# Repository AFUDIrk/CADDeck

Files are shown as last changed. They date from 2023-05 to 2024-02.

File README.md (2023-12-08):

# CADdeck
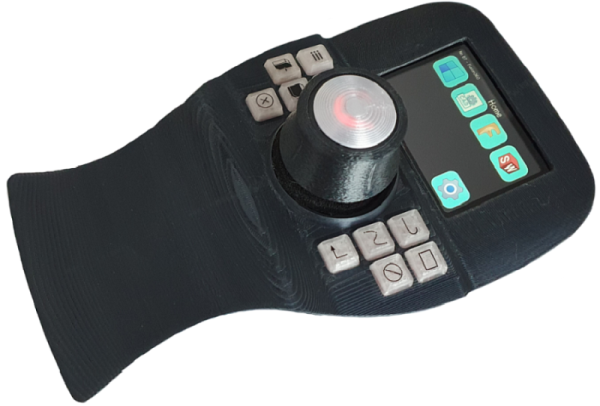
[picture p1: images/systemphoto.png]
Systemfoto


The english [Manual](/READMEeng.md) 

Hierbei handelt es sich um ein kombiniertes Joystick- und Touchpanel-Display, das für die Verwendung mit gängigen CAD-Programmen geeignet ist. Es beinhaltet:
1. Zwei-Achsen-Joystick (z. B. für X-, Y-Schwenk)
2. Hall-Sensoren im Joystick-Griff (z. B. für Zoom und Drehung) mit einem berührungslosen Sensor (z. B. zum Bewegen der Komponente in Kombination mit dem Joystick)
3. Zehn Schalter rund um die Basis (z. B. Messen, ESC...)
4. LCD-Touchpanel mit bis zu 10 Bildschirmen und 12 Tasten

Alle H/W-Tasten und die Touchpanel-Tasten sind über eine Website programmierbar.

Die Verbindung zum PC erfolgt per Bluetooth über die HID-Schnittstelle (d. h. für den PC sieht es aus wie eine Tastatur und eine Maus).
Für die Stromversorgung und das Herunterladen von Code steht ein USB-C-Anschluss zur Verfügung.
Der USB-C-Anschluss auf der Rückseite dient der Stromversorgung zum Hochladen des Codes.
Es sollte möglich sein, das Gerät mit Strom zu versorgen und es fest mit dem Bildschirm zu verbinden, anstatt es über USB-C mit Strom zu versorgen, aber das habe ich noch nicht versucht.

Es wurde von Andrew eine USB-Schnitstelle mit einem RP2040 hinzugefügt, mit der das CADDeck 6DOF fähig ist. Es wird noch daran gearbeitet, den Code so zu ändern,
das nur noch ein Prozessor gebraucht wird. Momentan ist noch eine Bluetooth- und eine USB-Verbindung nötig, damit das ganze funktioniert.

Die Firmware für den RP2040 ist von https://github.com/jfedor2/magellan-spacemouse.
Die Version für das CADDeck ist hier zu finden: https://github.com/AFUDIrk/magellan-spacemouse

## Touch-Panel
Das Touchpanel ist von Dustin Watts FreeTouchDeck-Projekt (https://github.com/DustinWatts/FreeTouchDeck.git) inspiriert, das ich modifiziert habe, um die Anzahl der Tasten zu erhöhen.
usw. (https://github.com/andrewfernie/FreeTouchDeckWT32.git). Für dieses Projekt habe ich Joystick-, Hallsensor- und Tastenunterstützung hinzugefügt.
Der einfachste Weg, dies in Gang zu bringen, ist die Verwendung einer WT32-SC01-Karte (http://www.wireless-tag.com/portfolio/wt32-sc01/).
Kaufen Sie das Basisboard, nicht die „Plus“-Version, da das Plus eine parallele Schnittstelle zum LCD-Panel nutzt und nicht genügend IO-Leitungen für den Joystick und die Tasten frei lässt.
usw. Das Board enthält ein ESP32-Modul und ein 3,5-Zoll-LCD mit kapazitivem Touchscreen.

## S/W-Aufbau-Hinweise:
1. Der Build verwendet die PlatformIO-IDE für VSCode. Installieren Sie VSCode, dann das PlatformIO-Plugin und schon kann es losgehen.
2. Sie müssen sicherstellen, dass die entsprechenden Pins für Ihre Hardwarekonfiguration definiert sind. Ich habe meines für den WT32-SC01 gebaut und den Code für ein handverdrahtetes ESP32-Modul + einen resistiven Touchscreen erstellt.
3. Möglicherweise sehen Sie Build-Meldungen wie
 
In der Datei, die aus include/CADDeck.h:14 enthalten ist,
aus include/SaveConfig.h:3,
von src/SaveConfig.cpp:1:
.pio/libdeps/esp-wrover-kit/TFT_eSPI/TFT_eSPI.h:909:8: Warnung: #warning >>>>------>> TOUCH_CS-Pin nicht definiert, TFT_eSPI-Touchfunktionen sind nicht zugänglich! [-Wcpp]
#Warnung >>>>------>> TOUCH_CS-Pin nicht definiert, TFT_eSPI-Touchfunktionen sind nicht verfügbar!`
 
Sie können diese beseitigen, indem Sie TOUCH_CS in platformio.ini für jeden nicht verwendeten Pin definieren, der ein gültiger Ausgabepin ist.
Die Alternative besteht darin, TOUCH_CS nicht zu definieren (die Zeile löschen oder ein Semikolon davor einfügen) und die Meldungen einfach zu ignorieren.

#define TOUCH_CS=33

4. Das System versucht beim Start, das Logo in CADDeck_logo.bmp anzuzeigen. Wenn Sie nicht möchten, dass etwas angezeigt wird, stellen Sie sicher, dass die Datei nicht existiert. In diesem Fall wird auf der seriellen Schnittstelle eine Meldung wie die folgende angezeigt.
Solange Sie beim Start nichts gesehen haben, ignorieren Sie die Meldung.
 
[ 1159][E][vfs_api.cpp:104] open(): /littlefs/logos/CADDeck_logo.bmp existiert nicht, keine Berechtigungen zum Erstellen

5. Möglicherweise werden Ihnen Fehlermeldungen wie z. B. angezeigt
 
[vfs_api.cpp:104] open(): /littlefs/list existiert nicht
 
Dies ist ein bekanntes Problem mit ESPAsyncWebsServer im Zusammenhang mit von LittleFS unterstützten Ordnern, während dies bei SPIFFS nicht der Fall ist. Siehe https://github.com/lorol/

6. Haben Sie Probleme? Es gibt einige Debug-Meldungen, die in FreeTouchDeck.h aktiviert werden können
 
#define LOG_MSG_BASIC 1
#define LOG_MSG_LEVEL 1 // 1=FEHLER, 2=FEHLER+WARN, 3=FEHLER+WARN+INFO
#define LOG_MSG_DEBUG 0
#define LOG_MSG_TOUCH_DEBUG 0 // Meldungen an die Konsole jedes Mal, wenn eine Berührung erkannt wird

Versuchen Sie, LOG_MSG_LEVEL auf 3 zu setzen, und Sie erhalten weitere Statusmeldungen

# Hardware-Aufbau

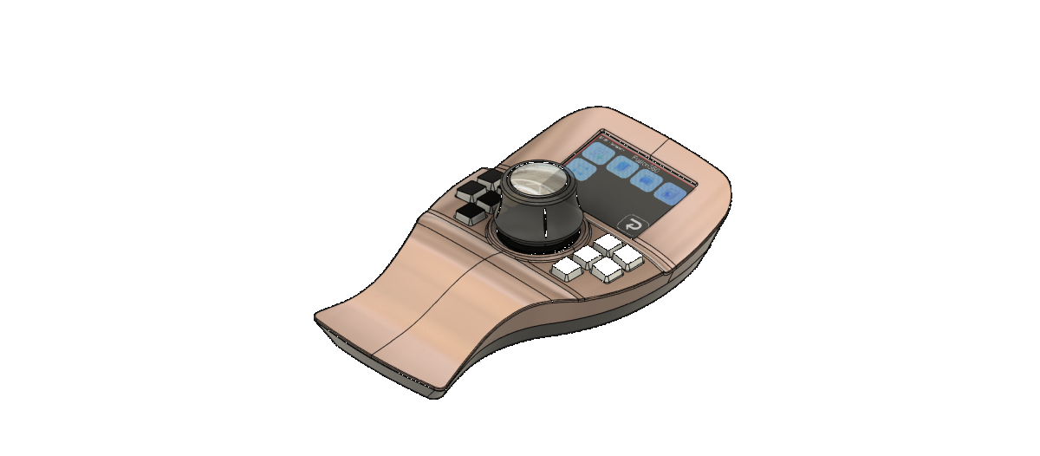
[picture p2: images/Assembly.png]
Assembly


Der größte Teil der Montage ist einfach und besteht größtenteils aus der Verkabelung.
Vollständige 3D-CAD-Modelle werden sowohl im Fusion360- als auch im STEP-Format im Ordner „hardware/model“ bereitgestellt.

Die Verweise auf Tastennummern werden in diesem Diagramm angezeigt:

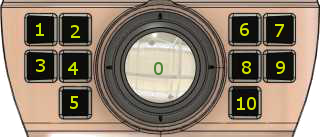
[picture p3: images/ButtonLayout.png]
Schaltflächennummern


## Gehäuse
Ein Fusion360-Modell des Falls und STL-Dateien sind im CADDeck-Repository enthalten. Das Hauptgehäuse ist zweiteilig bedruckt.
Das Ober- und Unterteil wird von unten mit M3-Kopfschrauben verschraubt.

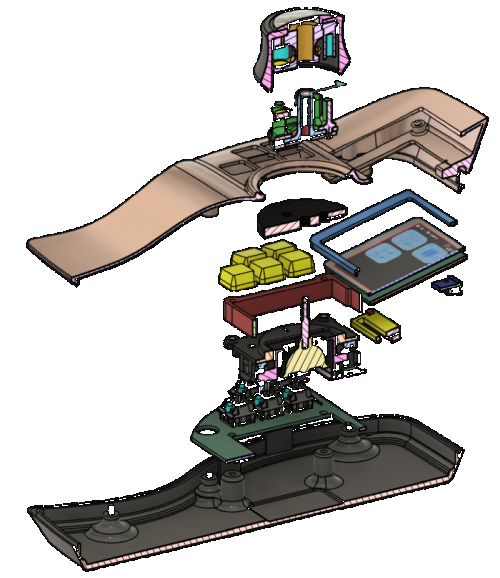
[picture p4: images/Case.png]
Case


Es gibt keine offensichtliche Möglichkeit, den Bildschirm am Gehäuse zu befestigen. Deshalb habe ich das Gehäuse so entworfen, dass es das Display mit einem Rahmen hält.
Zuerst wird das Display in das Gehäuse geschoben, bis es in den hinteren Abstandshaltern einrastet.
Anschließend wird die TPU-Dichtung zwischen Gehäuse und Display geschoben und abschließend die beiden vorderen Abstandshalter eingefügt.
Bei Bedarf kann das Display mit zwei Schrauben von hinten gegen die TPU-Dichtung gedrückt werden.
Aber war bei mir nicht nötig.

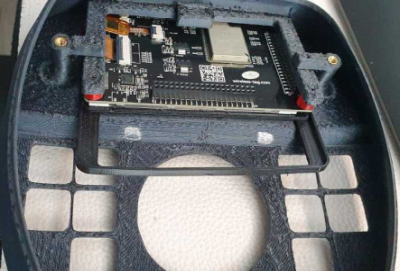
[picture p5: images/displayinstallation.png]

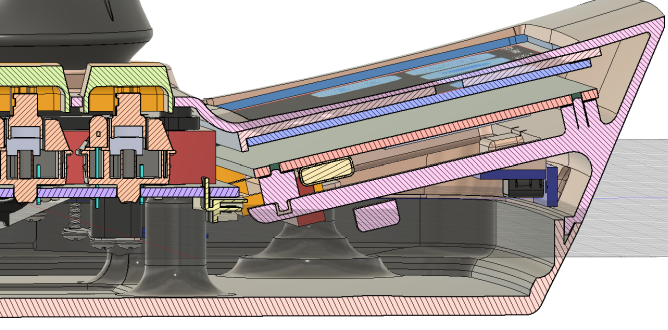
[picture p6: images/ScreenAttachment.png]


Die USB-C-Adapterplatine wird mit zwei selbstschneidenden Schrauben an der kleinen Basis befestigt.

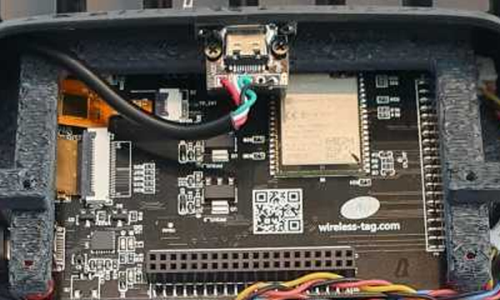
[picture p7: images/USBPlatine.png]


6 x M3-Flachkopfschrauben gehen durch die Unterseite des Gehäuses und dienen dazu, das Gehäuse geschlossen zu halten.
4 x M3-Flachkopfschrauben kommen durch die Unterseite des Gehäuses und dienen zur Befestigung sowohl des Joysticks als auch der Schalterplatte mit den 10 Schaltern.

## Joystick-Knopf

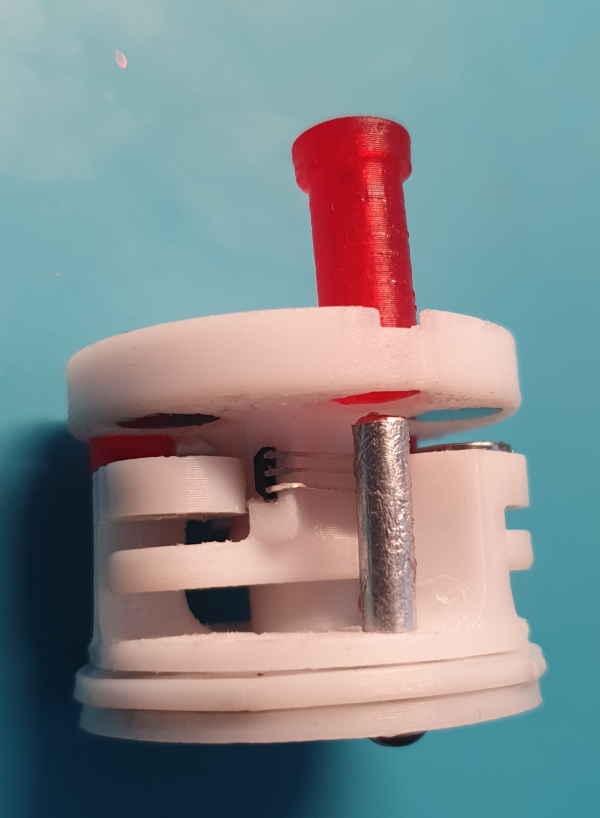
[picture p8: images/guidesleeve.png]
button


Der knifflige Teil ist die Joystick-Taste und insbesondere die Magnete und Hall-Sensoren. Der obere Hallsensor wird direkt eingeklebt
und das untere habe ich vorher auf eine kleine Lochmusterplatine gelötet und dann mit Sekundenkleber befestigt.
Für die Erstellung steht auch ein Platinenlayout zur Verfügung.
Platinen für die 10 Schalter und für den Taster habe ich bereits anfertigen lassen, dadurch ist der Aufbau übersichtlicher und die Verkabelung der MX-Taster entfällt.

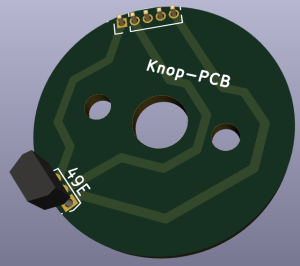
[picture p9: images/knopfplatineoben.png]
 
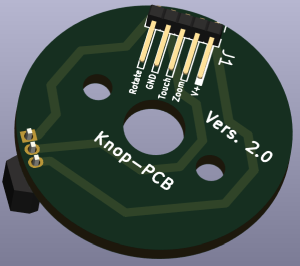
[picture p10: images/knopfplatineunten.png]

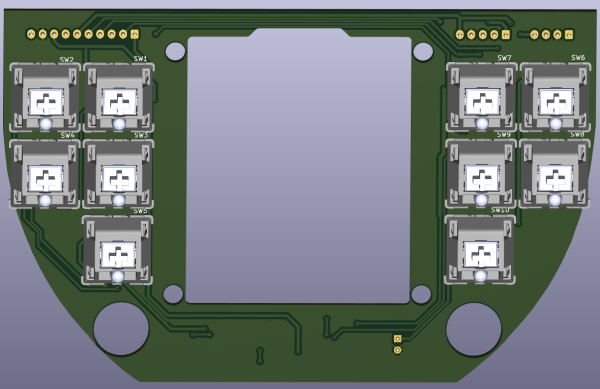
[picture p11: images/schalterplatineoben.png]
 
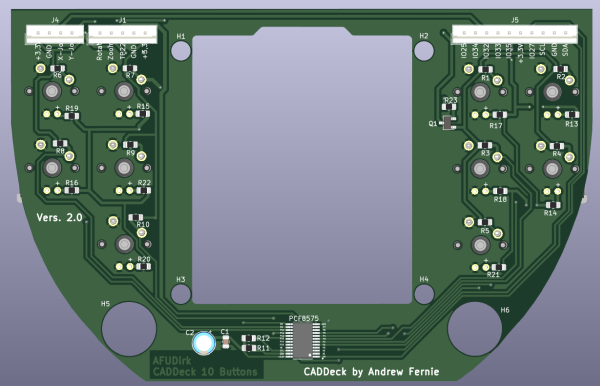
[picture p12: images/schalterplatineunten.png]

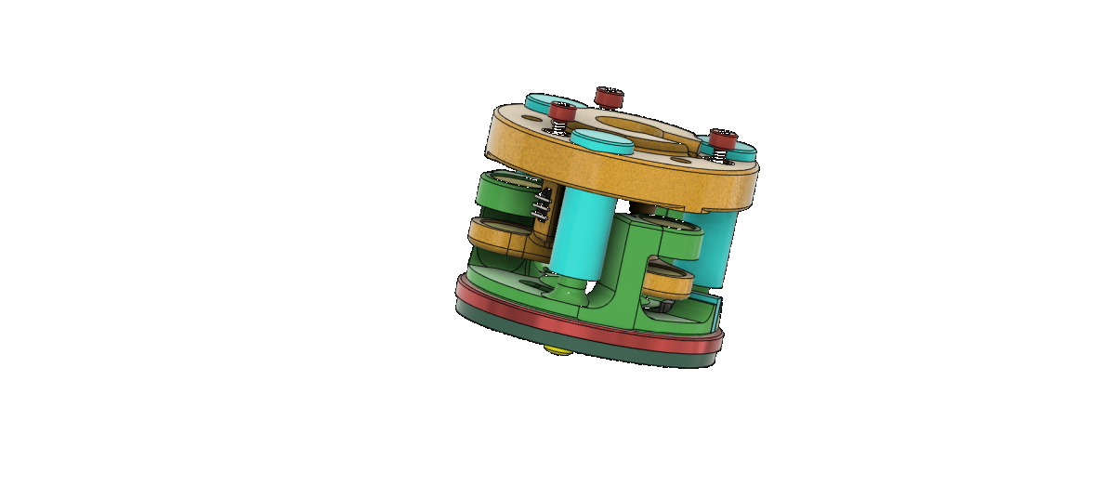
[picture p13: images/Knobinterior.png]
Knobinterior


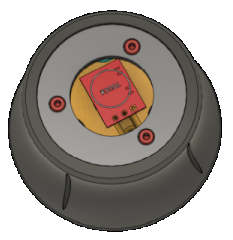
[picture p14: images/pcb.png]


Der Joystick-Knopf besteht aus mehreren 3D-gedruckten Teilen.
Im Inneren des Joystick-Knopfes befinden sich mehrere Magnete, die sich gegenseitig abstoßen und ihn so in einer schwebenden Position halten. Ich habe etwas Sekundenkleber verwendet
um die Magnete anzubringen. Sie können einfach einen Tropfen Sekundenkleber durch das kleine Loch im Kunststoff tropfen lassen.
Im Bildverzeichnis finden Sie eine Darstellung der Anordnung der Magnete (N+S).

Wenn alle Magnete montiert sind, werden das Kreuz und der Magnethalter vorsichtig zusammengesteckt und dann gedreht, sodass die Magnete übereinander liegen.
Anschließend werden die drei Führungsstifte mit etwas Fett eingesetzt, sie halten die beiden Teile zusammen.
Ein M4x16mm Abstandshalter aus Messing wird von oben in die Grundplatte eingedrückt (ggf. mit etwas Kleber fixieren).
Anschließend die Grundplatte mit etwas Fett von unten in das Kreuz einsetzen und auf Leichtgängigkeit achten.
Abhängig davon, wie genau Ihr Drucker druckt, muss die Achse möglicherweise bearbeitet werden.
Ich habe eine M4-Schraube in die Grundplatte geschraubt, diese in einen Akkuschrauber eingespannt und abgeschliffen, bis sie passte.
Die Bodenplatte mit den Magneten wird mit drei selbstschneidenden Schrauben befestigt.
Der Touchsensor wird mit Kleber am Deckel befestigt, der Deckel wird ganz am Ende in das Rad geschoben und sollte ohne Kleber halten.

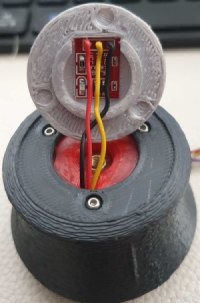
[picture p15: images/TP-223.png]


Die Drähte vom Berührungssensor und vom oberen Hallsensor werden durch Löcher nach unten geführt.
Bitte lassen Sie die Kabel etwas länger, da der Joystick-Knopf später auf den Joystick aufgedreht wird.

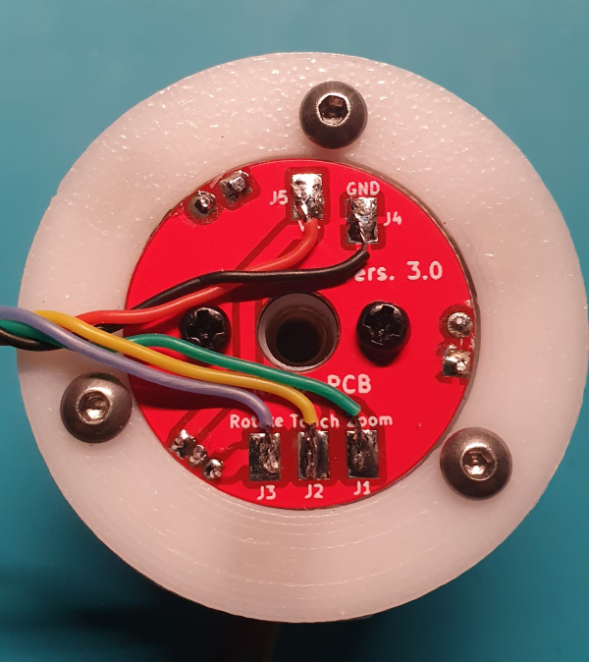
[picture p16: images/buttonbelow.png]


Alle 10 MX-Taster werden am Schaltpult genutzt und entsprechend dem Schaltplan verdrahtet.
Der PCF8575 wird mit selbstschneidenden Schrauben an der Adapterplatte befestigt.
Zuerst den Joystick von unten einsetzen, dann die Adapterplatte und dann die Schalterkonsole.
Setzen Sie den Schaumstoff von oben ein, drehen Sie dann den Joystick-Knopf auf den Joystick und verlegen Sie die Kabel nach unten unter den Schaumstoff.
Der Joystick-Knopf wird am Joystick befestigt und von oben mit einer M4-Stiftschraube gekontert, sodass er fest auf der Joystick-Achse sitzt.
Jetzt ist das Gehäuse zusammengebaut. Schrauben Sie zunächst alle Schrauben von unten locker ein. Ziehen Sie dann die sechs äußeren Schrauben fest.
Richten Sie nun die Schalterkonsole so aus, dass die Schalterkappen nicht verklemmen und ziehen Sie abschließend die letzten vier Schrauben fest.

Im Bilderverzeichnis gibt es noch ein paar Bilder, wie ich die Stütze ausgedruckt habe.

## Verkabelung
Ein [Schaltplan](hardware/Electrical/WiringDiagram10Buttons.pdf) ist im Ordner hardware/electrical enthalten. Das meiste davon ist unkompliziert.

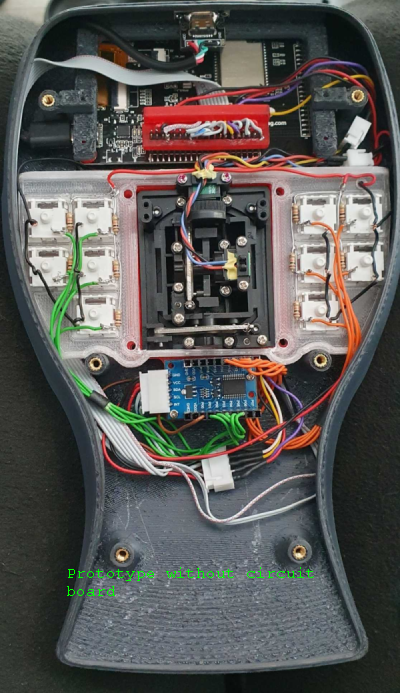
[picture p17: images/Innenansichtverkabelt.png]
Innenansicht


## Teileliste
Menge  1 [ESP32-SC01 LCD-Touchscreen] (https://www.aliexpress.com/item/1005004399769442.html)

Menge  1 [2mm 2x20 Pin Header](https://www.aliexpress.com/item/1005001852671581.html)

Menge  1 [Kapazitiver Berührungsschalter TTP223](https://www.aliexpress.com/i/33012282190.html)

Menge 10 [Cherry MX Button](https://www.ebay.de/itm/183967039197) (Diese gibt es in verschiedenen Ausführungen. Mit oder ohne Klick, starker oder leichter Widerstand.)

Menge  1 [FrSky M9 Joystick] (https://www.ebay.de/itm/374032459911) Dieses Gerät ist etwas teuer, aber von guter Qualität.
         Funktionell gibt es nichts Besonderes – man braucht nur etwas mit analogen X- und Y-Ausgängen.

Menge  1 [PCF8575 I2C IO Expander] (https://www.aliexpress.com/item/1005004433286881.html)

Menge  1 [USB-C-Adapterplatine] (https://www.aliexpress.com/item/1005003446036071.html)

Menge  2 [Hallsensoren 49E](https://www.aliexpress.com/item/1903819684.html)

Menge 40 [Klebe-Ausgleichsgewichte](https://www.ebay.de/itm/363221786745) (Bei Bedarf. Als ich den Knopf hochzog, war das Gehäuse zu leicht für mich.
         Sie können aber auch etwas anderes verwenden, um das Gewicht zu erhöhen.)

Menge 10 10k 1/8W Push-Through-Widerstände Cherry MX-Druckknopf

Menge  6 M3-Messingeinsätze (für Gehäuseoberseite)

Menge  3 M2-Messingeinsätze (für den Joystick-Knopf zum Befestigen des Rads)

Menge  3 selbstschneidende Schrauben 2,2x5mm (für Magnethalter unten)

Menge 11 Neodym-Magnete N52 5x5x1mm (9 Stück für die Drehbewegung und zwei Stück übereinander für den Hallsensor)

Menge  6 Neodym-Magnet N52 8x1mm (in der Joystick-Taste oben und unten)

Menge  3 Neodym-Magnet N52 8x3mm (im Joystick-Knopf in der Mitte)

Menge  6 Schrauben M3x10mm (für das Gehäuse)

Menge  4 Schrauben M3x20mm (zur Befestigung des Joysticks)

Menge  9 Schrauben M2x5mm (zur Befestigung des Rads an der Joystick-Taste, der USB-C-Platine und zur Befestigung des PCF8575)

Menge  1 M4x16mm Sechskant-Abstandsbolzen Innenknopf

Menge  1 JST RM 2,54 mm Stecker und Stiftleiste  5-polig

Menge  1 JST RM 2,54 mm Stecker und Stiftleiste  4-polig

Menge  1 JST RM 2,54 mm Stecker und Stiftleiste 10-polig

Leicht weicher Schaumstoff (zwischen Joystick-Taste und Joystick)

26 AWG (0,14 mm²) Silikondraht für die Verbindung zwischen den Platinen(vorzugsweise in mehreren Farben, um Verwechslungen zu vermeiden)

30 AWG (0,05 mm²) Silikondraht für den Knopf(vorzugsweise in mehreren Farben, um Verwechslungen zu vermeiden)

# Aufstellen
Sobald das Gerät zusammengebaut ist und das Display erscheint, sollten Sie die Hauptseite sehen.
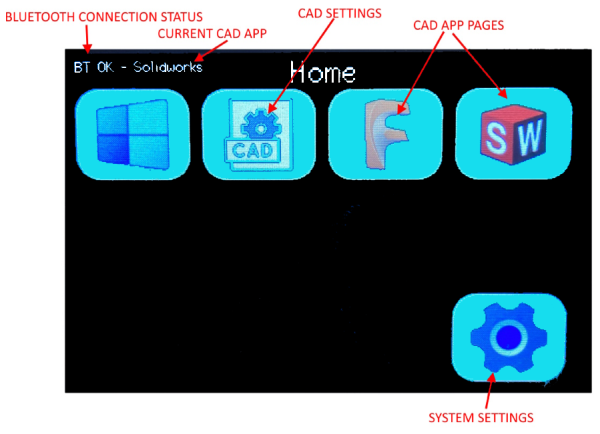
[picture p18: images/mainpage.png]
Hauptseite


Gehen Sie zur Seite CAD-Einstellungen.
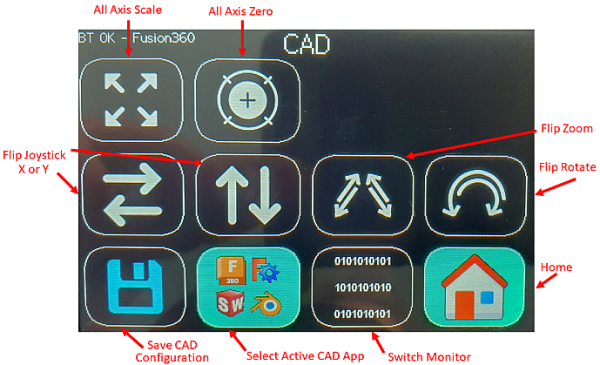
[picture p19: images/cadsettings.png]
CAD-Einstellungsseite


Dann die Seite Switch Monitor.

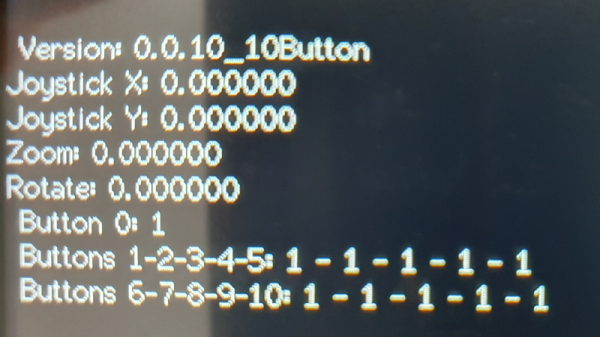
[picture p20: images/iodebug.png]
Monitorseite wechseln


Es zeigt den Status des Joysticks, des Push-Sensors und der Tasten an. Sie sollten das Ergebnis jeder Joystick-Bewegung oder Tastenauswahl sehen können.
Beachten Sie, dass die Werte als 1 angezeigt werden, wenn sie nicht ausgewählt sind, und als 0, wenn sie ausgewählt (gedrückt) sind.

Die X- und Y-Daten des Joysticks sowie die Dreh- und Zoomdaten können leicht schwanken. Das ist normal, da der Joystick zu diesem Zeitpunkt noch nicht kalibriert ist.
So kalibrieren Sie den Joystick und den Knopf:
1. Gehen Sie zurück zur Seite CAD-Einstellungen
2. Drücken Sie die Joystick-Nulltaste, wenn der Joystick zentriert und stationär ist. Dadurch wird der Nullpunkt für Joystick und Knopf festgelegt.
3. Drücken Sie die Joystick-Skalentaste und bewegen Sie den Joystick zum äußersten X- und Y-Punkt, drehen Sie den Knopf und drücken Sie ihn nach oben und unten.
   Du hast 5 Sekunden Zeit.
   Sobald die Funktion abgeschlossen ist, werden die Kalibrierungsparameter berechnet und alle Achsen sollten einen Bereich von ungefähr +/- 1 sowohl in X als auch in Y anzeigen.
4. Wenn Sie mit der Kalibrierung zufrieden sind, klicken Sie auf die Schaltfläche „CAD-Konfiguration speichern“ und die Parameter werden in der Datei cadparams.json im ESP32 gespeichert.
   Diese Datei kann vom ESP32 über die Seite CAD-Einstellungen im Konfigurator auf Ihren PC heruntergeladen werden.
   Es empfiehlt sich, dies zu tun und die Datei in den Ordner data\config im CADDeck-Code zu kopieren, damit Sie die Parameter nicht verlieren, wenn Sie den Datenordner das nächste Mal auf den ESP32 hochladen.
4. Wenn Sie mit den Ergebnissen nicht zufrieden sind, versuchen Sie es erneut.

Verbinden Sie Ihren Computer über die Bluetooth-Einstellungsseite Ihres Computers mit CADDeck.

# Konstruktion
Bitte beachten Sie, dass es sich bei allen oben gezeigten oder erwähnten Seiten um Beispiele handelt. Jede Seite kann über den Konfigurator neu organisiert und an Ihre Bedürfnisse angepasst werden.

## WLAN-Konfiguration
Der Zugriff auf den Konfigurator erfolgt über einen Webbrowser auf einem Computer oder Tablet, der mit demselben Netzwerk wie der ESP32 verbunden ist.
Um den Konfigurator zu aktivieren, gehen Sie auf die Einstellungsseite des Touchpanels und wählen Sie die Schaltfläche „WLAN aktivieren“.

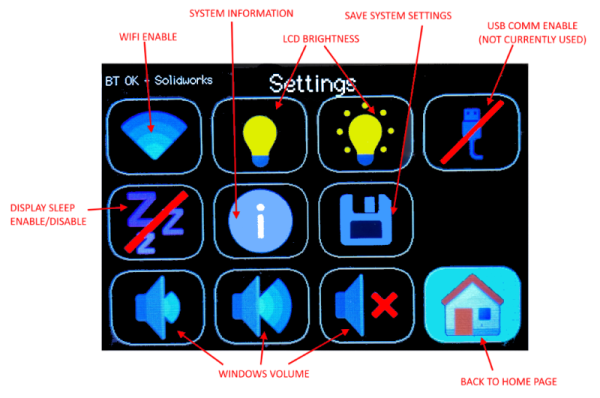
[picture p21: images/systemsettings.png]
Systemeinstellungen


Wenn Sie Ihre WLAN-Verbindung bereits in wificonfig.json konfiguriert haben, sollte eine Meldung angezeigt werden, dass das WLAN verbunden ist und die IP-Adresse angezeigt wird.
An dieser Stelle können Sie zu Ihrem Browser gehen und die IP-Adresse von top connect eingeben. Der Konfigurator wird angezeigt.

Hauptkonfiguratorseite

Wenn Sie das WLAN noch nicht konfiguriert haben, sollte eine Meldung angezeigt werden, dass ein Zugangspunkt (AP) mit einem Netzwerknamen und einer IP-Adresse erstellt wurde.
Sie müssen Ihren Computer mit dem bereitgestellten Netzwerk verbinden und dann Ihren Browser auf die IP-Adresse verweisen.
Sobald der Konfiguratorbildschirm in Ihrem Browser erscheint, gehen Sie zur WLAN-Seite und geben Sie Ihre Netzwerk-SSID und Ihr Passwort ein. Wählen Sie dann „Save WiFi Config“, um die Einstellungen zu speichern.

## Menükonfiguration
Die wichtigste Änderung gegenüber dem ursprünglichen FreeTouchDeck besteht darin, dass mehr Tasten pro Seite möglich sind – die Bildschirmfläche ist nur geringfügig kleiner als die Größe von zwölf StreamDeck-Tasten, was vernünftig erscheint.
Der Code ist derzeit auf drei Reihen mit je vier Schaltflächen eingestellt, kann jedoch durch Ändern von CADDeck.h in drei Reihen mit je fünf Schaltflächen (oder zwei Reihen mit je vier Schaltflächen usw.) geändert werden: „#define BUTTON_ROWS 3“ und „#define BUTTON_COLS 5“. „. ".
Grundsätzlich sollte es größere Arrays unterstützen, wurde aber nicht getestet und die Konfiguratorseite ist auf maximal 3x5 eingestellt.

Der Konfigurator zeigt eine Reihe von drei Reihen mit fünf Schaltflächen an, mit einer Dropdown-Liste zur Auswahl der zu ändernden Menüseite.
Wenn Sie weniger als 3x5 verwenden, ignorieren Sie einfach die zusätzlichen Zeilen und Spalten. Auf der To-Do-Liste steht die dynamische Generierung des HTML-Codes, um ihn an die Anzahl der Zeilen und Spalten anzupassen.
MenuConfigurator

Jede Menüseite verfügt über eine 2D-Reihe programmierbarer Tasten und jede Taste verfügt über eine Reihe von 3 Aktionen, die beim Drücken der Taste definiert werden können.

Sie können unterschiedliche Hintergrundfarben für eine Schaltfläche festlegen, die eine Aktion ausführt (schwarzer Hintergrund im Bild oben) oder für Links zu einem anderen Menü (hellblau im Bild).
Dies wird auf der Seite „Einstellungen“ des Konfigurators gesteuert.

Wenn Sie nicht alle Buttons nutzen möchten, stellen Sie im Konfigurator das Logo auf „blank.bmp“ ein und achten Sie darauf, dass für diesen Button keine Aktionen definiert sind.
Schaltflächen mit diesen Eigenschaften werden nicht gezeichnet.

Eine Einschränkung ist die Größe des FLASH, der für die auf dem Touchscreen angezeigten Konfigurationsdateien und Symbole verwendet wird. Bei den Symbolen handelt es sich um 75x75 24-Bit-Farb-BMP-Dateien.
Jeder benötigt etwa 17 KB. Wenn Ihnen der Speicherplatz ausgeht, besteht Ihre einzige Möglichkeit darin, zu prüfen, ob noch freier Speicherplatz vorhanden ist, und ihn zu löschen.

## Hardwareschlüssel
Die Hardwaretasten werden über eine spezielle Seite innerhalb desselben webbasierten Konfigurators wie für das LCD-Panel konfiguriert.
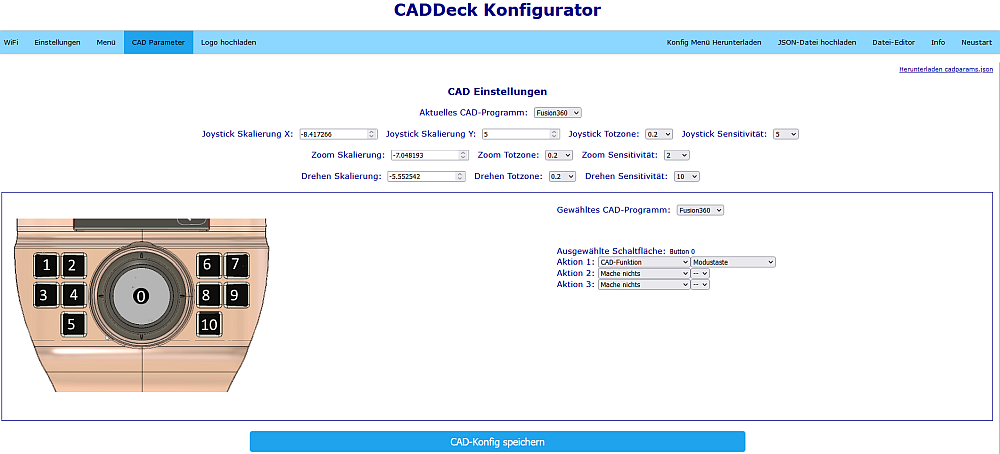
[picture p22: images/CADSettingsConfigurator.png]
CAD-Einstellungen-Konfigurator


Der obere Abschnitt umfasst:
1. Aktuelles CAD-Programm: Dies ist das Programm, dessen Einstellungen geladen werden, wenn CADDeck neu gestartet wird
2. X- und Y-Skalierungsparameter für Joystick und Knopf. Diese können manuell eingestellt werden
   Es gibt jedoch eine Funktion, die Daten sammelt, während der Joystick ganz nach unten gedrückt wird, und den Maßstab für Sie berechnet. Die Ausgabeskalierung beträgt +/-1
3. Deadzone von Joystick und Knopf. Jeder X- oder Y-Wert mit einem absoluten Wert unter dieser Zahl wird auf Null gesetzt.
4. Joystick-Empfindlichkeit. Joystick-Werte werden bei der Umwandlung in Mausbewegungsbefehle damit multipliziert
5. Empfindlichkeit des Knopfes. Der Knob-Wert wird damit multipliziert und in Mausbewegungsbefehle umgewandelt
6. Steady Time: Nachdem der Joystick länger als diese Zeitspanne zentriert war, ohne dass eine Schwenk- oder Drehtaste ausgewählt wurde, kehrt der Joystick in seinen Standardmodus (normalerweise Mauszeiger) zurück.

Darunter befindet sich die Definition der Tastenaktion. Zur Definition der Aktionen wird derselbe Ansatz wie für die Tasten auf dem LCD-Panel verwendet. Die Aktionen sind:
1. Ausgewähltes CAD-Programm. Das Programm, dessen Einstellungen in diesem Teil des Konfigurators geändert werden. Für jedes der fünf verfügbaren CAD-Programme werden separate Definitionen dieser Einstellungen gepflegt.
2. Ausgewählte Schaltfläche. Eine der neun im Bild links gezeigten Schaltflächen. Klicken Sie auf einen der angegebenen Bereiche im Bild und ändern Sie dann die Aktionen für diese Schaltfläche nach Bedarf.
3. Die Aktionen, die ausgeführt werden müssen, damit der Joystick (z. B. die Maus) das Schwenken/Drehen/Zoomen im ausgewählten CAD-Programm steuern kann.
Beachten Sie, dass die Definition dessen, was zum Steuern von Schwenken/Drehen/Zoomen erforderlich ist, unabhängig davon ist, welche Taste diesen Modus aktiviert.
Beispielsweise muss bei Solidworks die mittlere Maustaste gedrückt gehalten werden, um die Ansicht zu drehen. Daher ist „JoystickRotate/Action1“ auf „Maustasten“ und „Value1“ auf „Drücken Sie die mittlere Taste“ eingestellt.
Um die Funktion „Drehen“ der Schaltfläche 8 zuzuweisen, klicken Sie im Bild links auf 8 und setzen Sie dann „SelectedButton/Action1“ auf „CAD Functions“ und „Value1“ auf „Joystick Rotate“.

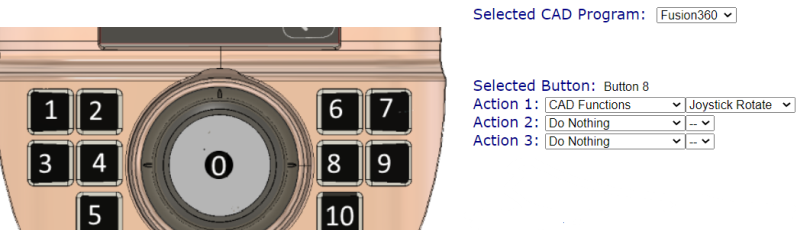
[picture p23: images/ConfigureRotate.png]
Drehfunktion konfigurieren


Unten befindet sich die Schaltfläche „CAD-Konfiguration speichern“. Bei Auswahl werden die Einstellungen für alle CAD-Programme auf dem ESP32 in der Datei caparams.json gespeichert

## Standardkonfiguration
Während über den Konfigurator alles geändert werden kann, gibt es einige Standardeinstellungen, die mit dem Code bereitgestellt werden.
Diese sind:

### Kontrollzuweisungen
1. Joystick bewegt die Komponente
2. Joystick mit gedrücktem Drucksensor (0), bewegt das Bauteil
3. Durch Drehen des Joystick-Knopfes wird die Ansicht gedreht
4. Durch Drücken oder Ziehen der Joystick-Taste wird vergrößert bzw. verkleinert
5. Schaltfläche 1 ist die Modellsymbolleiste („S“ in Fusion360).
6. Schaltfläche 2 ist Filet („F“ in Fusion360)
7. Taste 3 ist Push Pull („Q“ in Fusion360)
8. Schaltfläche 4 ist Extrudieren („E“ in Fusion360)
9. Mit Taste 5 wird die Auswahl aufgehoben („ESC“ in Fusion360 und Solidworks).
10. Schaltfläche 6 ist Linie („L“ in Fusion360)
11. Schaltfläche 7 ist ein Rechteck mit zwei Punkten („R“ in Fusion360)
12. Schaltfläche 8 ist Spline (ich habe es in Fusion360 auf „W“ gesetzt)
13. Schaltfläche 9 ist ein Kreis („C“ in Fusion360)
14. Schaltfläche 10 ist Zeile („Zurück“ in Fusion360)

### Menüs
Menünummern werden wie folgt vergeben:
1. Menü 0: Hauptmenü
2. Menü 1: Systemeinstellungen
3. Menü 2: CAD-Einstellungen
4. Menü 3: Nicht verwendet
5. Menü 4: Nicht verwendet
6. Menü 5: Nicht verwendet
7. Menü 6: Nicht verwendet
8. Menü 7: Aktives CAD-Programm auswählen
9. Menü 8: Fusion360-Aktionen
10. Menü 9: Nicht verwendet
 
Wenn Sie Unterstützung bei der Einrichtung oder beim Beschaffen der Platinen benötigen,
können Sie meinem Discord-Server beitreten.https://discord.gg/kFvPhqmc

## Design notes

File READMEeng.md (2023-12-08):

# CADdeck
system photo

This is a combined joystick and touch panel display that is suitable for use with common CAD programs. It contains:
1. Two-axis joystick (e.g. for X, Y pan)
2. Hall sensors in the joystick handle (e.g. for zoom and rotation) with a non-contact sensor (e.g. for moving the component in combination with the joystick)
3. Ten switches around the base (e.g. measure, ESC...)
4. LCD touch panel up to 10 screens with 12 keys

All H/W keys and the touch panel keys are programmable via a website.

The connection to the PC is via Bluetooth via the HID interface (ie to the PC it looks like a keyboard and mouse).
A USB-C port is available for power and code downloading.
The USB-C port on the back is for power to upload the code.
It should be possible to power the device and hard-wired it to the screen instead of using USB-C for power, but I haven't tried that.

Andrew added a USB interface with an RP2040 with which the CADDeck is 6DOF capable. We are still working on changing the code so
that only one processor is needed. At the moment a Bluetooth and a USB connection are required for the whole thing to work.

The firmware for the RP2040 is from https://github.com/jfedor2/magellan-spacemouse.
The version for the CADDeck can be found here: https://github.com/AFUDIrk/magellan-spacemouse

## Touch panel
The touch panel is inspired by Dustin Watt's FreeTouchDeck project (https://github.com/DustinWatts/FreeTouchDeck.git), which I modified to increase the number of buttons.
etc. (https://github.com/andrewfernie/FreeTouchDeckWT32.git). For this project I added joystick, Hallsensor and button support.
The easiest way to get this going is to use a WT32-SC01 card (http://www.wireless-tag.com/portfolio/wt32-sc01/).
Buy the base board, not the "Plus" version, as the Plus uses a parallel interface to the LCD panel and doesn't leave enough IO lines free for the joystick and buttons.
etc. The board contains an ESP32 module and a 3.5 inch LCD with a capacitive touchscreen.

## S/W Build Notes:
1. The build uses the PlatformIO IDE for VSCode. Install VSCode, then the PlatformIO plugin and you're good to go.
2. You must ensure that the appropriate pins are defined for your hardware configuration. I built mine for the WT32-SC01 and created the code for a hand wired ESP32 module + resistive touch screen.
3. You may see build messages like
 
In the file included from include/CADDeck.h:14,
from include/SaveConfig.h:3,
from src/SaveConfig.cpp:1:
.pio/libdeps/esp-wrover-kit/TFT_eSPI/TFT_eSPI.h:909:8: Warning: #warning >>>>------>> TOUCH_CS pin not defined, TFT_eSPI touch functions are not accessible! [-Wcpp]
#Warning >>>>------>> TOUCH_CS pin not defined, TFT_eSPI touch functions are not available!`
 
You can get rid of these by defining TOUCH_CS in platformio.ini for each unused pin that is a valid output pin.
The alternative is to not define TOUCH_CS (delete the line or add a semicolon in front of it) and just ignore the messages.

#define TOUCH_CS=33

4. The system will attempt to display the logo in CADDeck_logo.bmp on startup. If you don't want anything to show up, make sure the file doesn't exist. In this case, a message like the following is displayed on the serial interface.
As long as you didn't see anything at startup, ignore the message.
 
[ 1159][E][vfs_api.cpp:104] open(): /littlefs/logos/CADDeck_logo.bmp does not exist, no permissions to create

5. You may get error messages such as B. displayed
 
[vfs_api.cpp:104] open(): /littlefs/list does not exist
 
This is a known issue with ESPAsyncWebsServer related to LittleFS-backed folders, while SPIFFS is not. See https://github.com/lorol/

6. Having problems? There are some debug messages that can be enabled in FreeTouchDeck.h
 
#define LOG_MSG_BASIC 1
#define LOG_MSG_LEVEL 1 // 1=ERROR, 2=ERROR+WARN, 3=ERROR+WARN+INFO
#define LOG_MSG_DEBUG 0
#define LOG_MSG_TOUCH_DEBUG 0 // Messages to the console each time a touch is detected

Try setting LOG_MSG_LEVEL to 3 and you'll get some more status messages

# Hardware build

Assembly

Most of the assembly is easy and mostly consists of the wiring.
Complete 3D CAD models are provided in both Fusion360 and STEP format in the hardware/model folder.

The references to button numbers are shown in this diagram:

button numbers

## case
A Fusion360 model of the case and STL files are included in the CADDeck repository. The main case is printed in two parts.
The upper and lower part is screwed from below with M3 head screws.

Case

There is no obvious way to attach the screen to the case. So I designed the case to hold the display with a frame.
First, the display is slid into the case until it snaps into the rear standoffs.
Then the TPU seal is pushed between the housing and the display and finally the two front spacers are inserted.
If necessary, the display can be pressed against the TPU seal from behind with two screws.
But wasn't necessary for me.

screen attachment
Screen Attachment

The USB-C adapter board is attached to the small base with two self-tapping screws.

screen attachment

6 x M3 pan head screws go through the bottom of the case and are used to hold the case closed.
4 x M3 pan head screws come through the bottom of the case and are used to attach both the joystick and the switch plate with the 10 switches.

## Joystick button

button

The tricky part is the joystick button and in particular the magnets and hall sensors. The upper Hall sensor is glued in directly
and the lower one I soldered to a small hole pattern circuit board beforehand and then attached it with superglue.
A circuit board layout is also provided to have this made.
I have already had circuit boards made for the 10 switches and for the button, this makes the structure cleaner and there is no need to wire the MX buttons.

![PCB] (images/Knopfplatine_oben.png) (images/Knopfplatine_unten.png) 

![PCB] (images/Schalterplatine_oben.png) (images/Schalterplatine_unten.png)

PCB 
PCB
PCB 
PCB								   
Knobinterior

button

The joystick button consists of several 3D printed parts.
Inside the joystick knob are several magnets that repel each other, keeping it in a floating position. I used a little super glue
to attach the magnets. You can just run a drop of superglue through the small hole in the plastic.
In the index of images you will find a representation of the arrangement of the magnets (N+S).

When all magnets are mounted, the cross and the magnet holder are carefully put together and then turned so that the magnets are on top of each other.
Then the three guide pins are inserted with a little grease, they hold the two parts together.
An M4x16mm spacer made of brass is pressed into the base plate from above (fix with some glue if necessary).
Then insert the base plate into the cross from below with a little grease and make sure it moves easily.
Depending on how accurate your printer is printing, the axis may need some editing.
I screwed an M4 screw into the base plate, clamped it in a cordless screwdriver and sanded it down until it fitted.
The bottom plate with the magnets is attached with three self-tapping screws.
The touch sensor is attached to the lid with glue, the lid is pushed into the wheel at the very end and should hold without glue.

button

The wires from the touch sensor and top hall sensor are routed down through holes.
Please leave the cables a little longer as the joystick knob will be twisted onto the joystick later.

button

All 10 MX buttons are used on the switching console and wired according to the circuit diagram.
The PCF8575 is attached to the adapter plate with self-tapping screws.
First insert the joystick from below, then the adapter plate and then the switch console.
Insert the foam from the top, then twist the joystick knob onto the joystick and route the cables down under the foam.
The joystick button is attached to the joystick and countered from above with an M4 stud screw so that it sits firmly on the joystick axis.
Now the case is assembled. First loosely screw in all the screws from below. Then tighten the six outer screws.
Now align the switch console so that the switch caps do not jam and finally tighten the last four screws.

In the picture directory there are a few more pictures of how I printed out the support.

## wiring
A [Wiring Diagram](hardware/Electrical/WiringDiagram10Buttons.pdf) is included in the hardware/electrical folder. Most of this is straightforward.

Inside view

## List of parts
Quantity 1 [ESP32-SC01 LCD Touch Screen] (https://www.aliexpress.com/item/1005004399769442.html)

Quantity 1 [2mm 2x20 Pin Header](https://www.aliexpress.com/item/1005001852671581.html)

Quantity 1 [Capacitive Touch Switch TTP223](https://www.aliexpress.com/i/33012282190.html)

Quantity 10 [Cherry MX Button](https://www.ebay.de/itm/183967039197) (These come in different designs. With or without a click, strong or light resistance.)

Quantity 1 [FrSky M9 Joystick] (https://www.ebay.de/itm/374032459911) This device is a bit expensive but good quality.
Functionally, there's nothing fancy - you just need something with analog X and Y outputs.

Quantity 1 [PCF8575 I2C IO Expander] (https://www.aliexpress.com/item/1005004433286881.html)

Quantity 1 [USB-C Adapter Board] (https://www.aliexpress.com/item/1005003446036071.html)

Quantity 2 [Hall Sensors 49E](https://www.aliexpress.com/item/1903819684.html)

Quantity 40 [Adhesive Balance Weights](https://www.ebay.de/itm/363221786745) (If needed. When I pulled up the knob, the case was too light for me.
But you can also use something else to add weight.)

Quantity 10 10k 1/8W push through resistors Cherry MX push button

Quantity 6 M3 brass inserts (for case top)

Quantity 3 M2 brass inserts (for the joystick button to attach the wheel)

Quantity 3 self-tapping screws 2.2x5mm (for magnet holder below)

Quantity 11 neodymium magnets N52 5x5x1mm (9 pieces for the rotary movement and two pieces on top of each other for the hall sensor)

Quantity 6 neodymium magnet N52 8x1mm (in the joystick button above and below)

Quantity 3 neodymium magnet N52 8x3mm (inside the joystick button in the middle)

Quantity 6 screws M3x10mm (for the housing)

Quantity 4 screws M3x20mm (for attaching the joystick)

Quantity 9 screws M2x5mm (to attach the wheel to the joystick button, the USB-C board and to attach the PCF8575)

Quantity 1 M4x16mm hex standoff Inside Knob

Quantity 1 JST RM 2,54 mm connector and pin header  5-pin

Quantity 1 JST RM 2.54mm male and female header 4 pin

Quantity 1 JST RM 2.54mm male and female header 10 pin

Slightly soft foam (between joystick button and joystick)

26 AWG (0.14mm²) silicone wire (preferably in multiple colors to avoid confusion)

# Set up
Once the device is assembled and the display appears, you should see the main page.
main page

Go to the CAD Settings page.
CAD Settings Page

Then the Switch Monitor page.

switch monitor side

It shows the status of the joystick, Push-Sensor and buttons. You should be able to see the result of each joystick movement or button selection.
Note that the values are shown as 1 when unselected and 0 when selected (pressed).

The joystick X and Y data and the rotate and zoom data may fluctuate slightly. This is normal as the joystick has not yet been calibrated at this point.
To calibrate the joystick and knob:
1. Go back to the CAD Settings page
2. Press the joystick zero button when the joystick is centered and stationary. This sets the zero point for the joystick and knob.
3. Press the joystick scale button and move the joystick to the extreme X and Y point, rotate the knob and push it up and down.
You have 5 seconds.
Once the function is complete, the calibration parameters will be calculated and all axes should show a range of approximately +/- 1 in both X and Y.
4. When you are satisfied with the calibration, click the "Save CAD Configuration" button and the parameters will be saved in the cadparams.json file in the ESP32.
This file can be downloaded to your PC from the ESP32 via the CAD Settings page in the Configurator.
It's a good idea to do this and copy the file to the data\config folder in the CADDeck code so you don't lose the parameters the next time you upload the data folder to the ESP32.
4. If you are not satisfied with the results, try again.

Connect your computer to CADDeck using your computer's Bluetooth settings page.

# Construction
Please note that all pages shown or mentioned above are examples. Each page can be reorganized and adapted to your needs via the configurator.

## WLAN configuration
The configurator is accessed via a web browser on a computer or tablet connected to the same network as the ESP32.
To activate the configurator, go to the settings page on the touch panel and select the "Activate WiFi" button.

System Settings

If you have already configured your WiFi connection in wificonfig.json, you should see a message that the WiFi is connected and the IP address is displayed.
At this point you can go to your browser and enter the IP address of top connect. The configurator is displayed.

main configurator page

If you haven't already configured the WiFi, you should see a message that an access point (AP) has been created with a network name and IP address.
You need to connect your computer to the provided network and then point your browser to the IP address.
Once the configurator screen appears in your browser, go to the WiFi page and enter your network SSID and password. Then select “Save WiFi Config” to save the settings.

## Menu configuration
The main change from the original FreeTouchDeck is allowing more buttons per side - the screen real estate is only slightly smaller than the size of twelve StreamDeck buttons, which seems reasonable.
The code is currently set to three rows of four buttons, but can be changed to three rows of five buttons (or two rows of four, etc.) by changing CADDeck.h: "#define BUTTON_ROWS 3" and "#define BUTTON_COLS 5 “. ".
In principle it should support larger arrays, but has not been tested and the configurator page is set to a maximum of 3x5.

The configurator displays a series of three rows of five buttons, with a drop-down list for selecting the menu page to change.
If you're using less than 3x5, just ignore the extra rows and columns. On the to-do list is to dynamically generate the HTML to fit the number of rows and columns.
MenuConfigurator

Each menu page has a 2D row of programmable buttons and each button has a row of 3 actions that can be defined when the button is pressed.

You can set different background colors for a button that performs an action (black background in the image above) or for links to another menu (light blue in the image).
This is controlled on the Settings page of the configurator.

If you don't want to use all buttons, set the logo to "blank.bmp" in the configurator and make sure that no actions are defined for this button.
Buttons with these properties are not drawn.

One limitation is the size of the FLASH used for the configuration files and icons displayed on the touch screen. The icons are 75x75 24-bit color BMP files.
Each takes about 17 KB. If you are running out of disk space, your only option is to check if there is any free disk space and delete it.

## Hardware keys
The hardware buttons are configured via a dedicated page within the same web-based configurator as for the LCD panel.
CAD Settings Configurator

The top section includes:
1. Current CAD program: This is the program whose settings will be loaded when CADDeck is restarted
2. X and Y scaling parameters for the joystick and knob. These can be set manually
   However, there is a feature that collects data while the joystick is pushed all the way down and calculates the scale for you. The output scaling is +/-1
3. Joystick and Knob Deadzone. Any X or Y value with an absolute value below this number will be set to zero.
4. Joystick Sensitivity. Joystick values are multiplied by this when converted to mouse movement commands
5. Knob sensitivity. The Knob value is multiplied by this while being converted to mouse movement commands
6. Steady Time: After the joystick has been centered for more than this amount of time without a pan or rotate button being selected, the joystick will revert to its default mode (usually mouse pointer).

Below that is the definition of the button action. The same approach is used to define the actions as for the buttons on the LCD panel. The actions are:
1. Selected CAD program. The program whose settings are changed in this part of the configurator. Separate definitions of these settings are maintained for each of the five available CAD programs.
2. Selected button. One of the nine buttons shown in the image on the left. Click on one of the specified areas in the image, and then change the actions for that button as needed.
3. The actions that need to be performed to allow the joystick (ie mouse) to control pan/rotate/zoom in the selected CAD program.
Note that the definition of what is required to control pan/rotate/zoom is independent of which button activates that mode.
For example, with Solidworks, the middle mouse button must be held down to rotate the view. Therefore, "JoystickRotate/Action1" is set to "Mouse Buttons" and "Value1" is set to "Press the middle button".
To assign the Rotate function to button 8, click 8 in the image on the left, then set SelectedButton/Action1 to CAD Functions and Value1 to Joystick Rotate.

Configure Rotate Function

At the bottom is the "Save CAD configuration" button. When selected, the settings for all CAD programs on the ESP32 are stored in the caparams.json file

## Default configuration
While everything can be changed via the configurator, there are some default settings that are provided with the code.
These are:

### Control assignments
 1. Joystick moves the component
 2. Joystick with pressed push sensor (0), moves the component
 3. Rotating the joystick knob rotates the view
 4. Pushing or pulling the joystick button zooms in and out
 5. Button 1 is Model Toolbar ("S" in Fusion360)
 6. Button 2 is Fillet ("F" in Fusion360)
 7. Button 3 is Push Pull ("Q" in Fusion360)
 8. Button 4 is Extrude ("E" in Fusion360)
 9. Button 5 deselects ("ESC" in Fusion360 and Solidworks)
10. Button 6 is Line ("L" in Fusion360)
11. Button 7 is a rectangle with two dots ("R" in Fusion360)
12. Button 8 is Spline (I set it to "W" in Fusion360)
13. Button 9 is circle ("C" in Fusion360)
14. Button 10 is line ("Return" in Fusion360)

### Menus
Menu numbers are assigned as follows:
1. Menu 0: Main menu
2. Menu 1: System settings
3. Menu 2: CAD settings
4. Menu 3: Not used
5. Menu 4: Not used
6. Menu 5: Not used
7. Menu 6: Not used
8. Menu 7: Select active CAD program
9. Menu 8: Fusion360 Actions
10. Menu 9: Not used
 
If you need assistance with setup or sourcing the boards,
you can join my discord server.https://discord.gg/kFvPhqmc

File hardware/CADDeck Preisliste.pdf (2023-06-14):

Stück | Bezeichnung | Preis
11 Neodym-Magnet N52 5x5x1 mm | 4,40
6 Neodym-Magnet N52 8x1 mm | 3,00
3 Neodym-Magnet N52 8x3 mm | 0,75
6 RUTHEX Gewindeeinsatz M3 | 0,54
3 RUTHEX Gewindeeinsazz M2 | 0,40
6 Zylinderschraube DIN912 M3x10 Gehäuse | 1,35
4 Zylinderschraube DIN912 M3x20 Joystick | 0,90
3 Zylinderschraube DIN912 M2x5 Rad | 0,60
3 Blechschraube 2,2x5(Magnethalter unten) | 0,60
1 Distansbolzen 4x16mm Messing | 0,35
1 USB-C Adapter-Platine | | 4,00
1 ESP32 WT32-SC01 | | 35,00
2 Hallsensoren 49E | | 0,50
1 FrSky TARANIS X9D Plus M9 Gimbal mit Hall-Sensoren | 29,00
1 TTP223 Kapazitive Touch-Switch-Taste | 6,00
40 5g Auswucht Klebegewichte (bei Bedarf) | 2,50
1 Tastenplatine unbestückt | 1,60
1 Knopfplatine unbestückt | 0,40
| Bestückung Schalterplatine
10 Cherry MX Taster | | 6,00
1 PCF8575 | | 1,00
1 2N 2222A SMD | | 0,04
1 SMD Widerstand 0805 1 KOhm | 0,33
10 SMD Widerstand 0805 100 Ohm (Tastenbeleuchtung) | 0,33
10 SMD Widerstand 0805 10 KOhm | 0,33
10 LED 3mm (Tastenbeleuchtung) | 1,40
1 JST Stiftleiste gewinkelt 5 pol RM 2,54 | 0,40
1 JST Stiftleiste gewinkelt 4 pol RM 2,54 | 0,40
1 JST Stiftleiste gewinkelt 10 pol RM 2,54 | 0,40
1 JST Steckerleiste 5 pol RM 2,54 | 0,40
1 JST Steckerleiste 4 pol RM 2,54 | 0,40
1 JST Steckerleiste 10 pol RM 2,54 | 0,40
1 Stiftleiste 2x20pol RM 2,0 | 1,70
| Schaltlitze 0,14 mm² 26 AWG
| Schaltlitze 0,05 mm² 30 AWG Knopf
| | 105,42

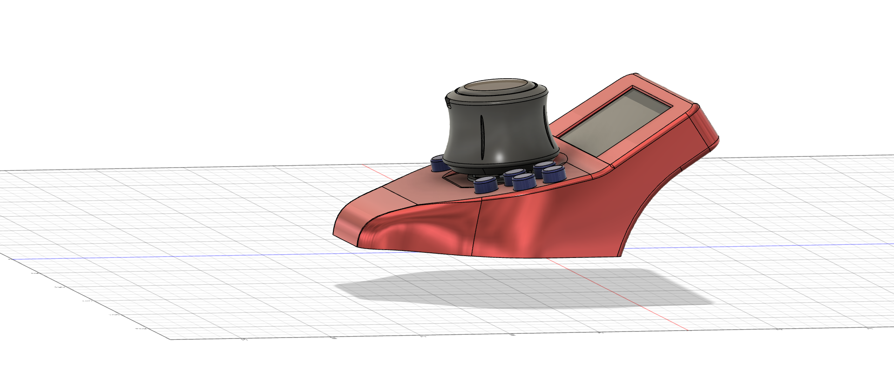
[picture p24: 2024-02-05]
hardware/New_Case/CADDeck2_2.png

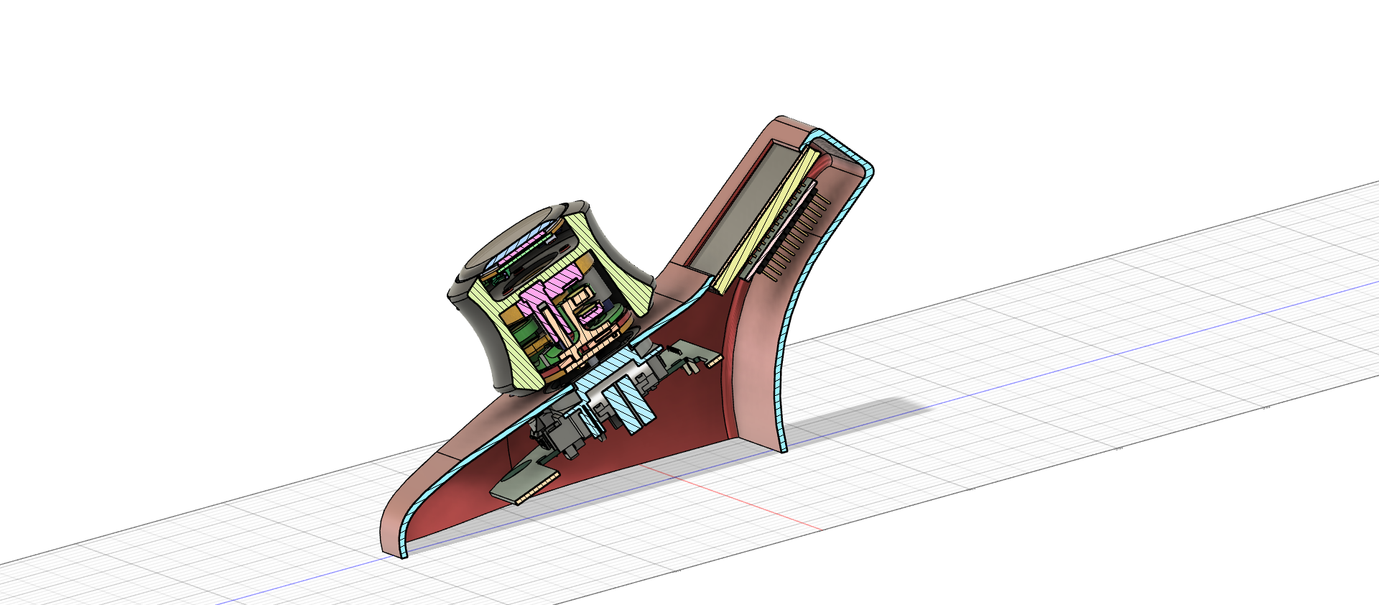
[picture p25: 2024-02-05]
hardware/New_Case/CADDeck2_1.png

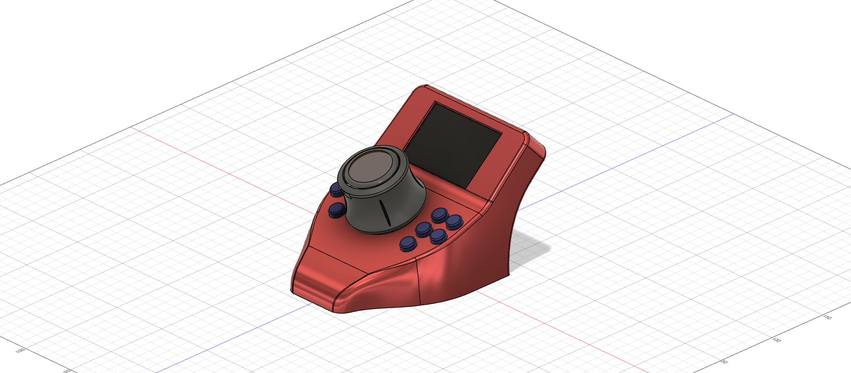
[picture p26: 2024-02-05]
hardware/New_Case/CADDeck2.png

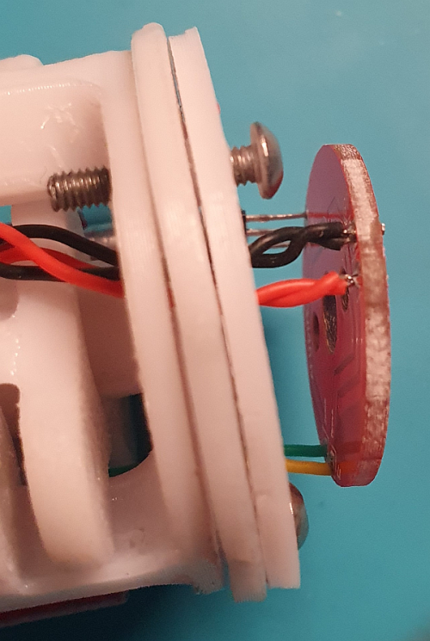
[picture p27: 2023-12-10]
images/Hall_Rotate.png

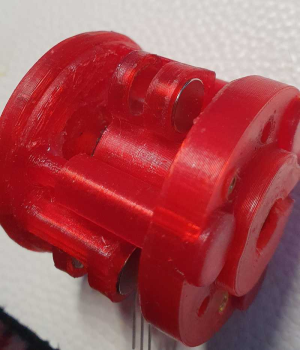
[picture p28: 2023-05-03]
images/Mag Zoom.png

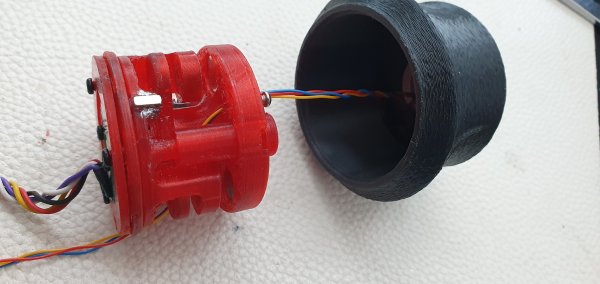
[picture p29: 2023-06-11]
images/Kabel_Pushsensor.png

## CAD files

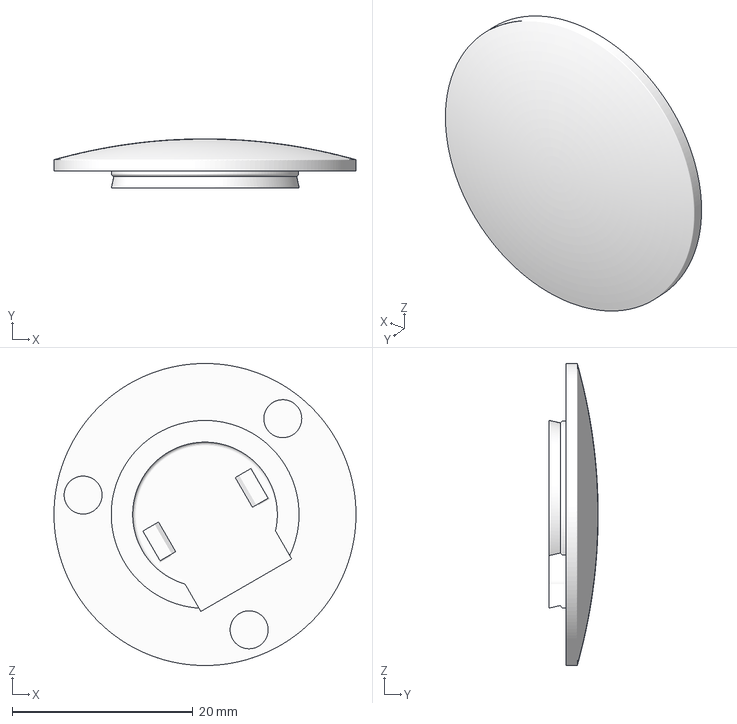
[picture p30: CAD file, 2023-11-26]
hardware/Case/Deckel.3mf
33.4 x 5.45 x 33.4 mm

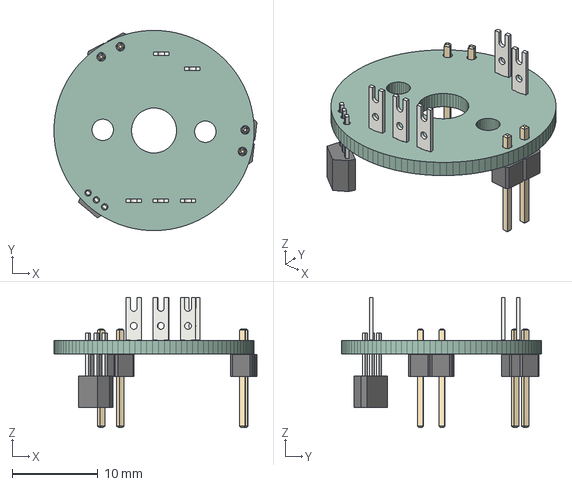
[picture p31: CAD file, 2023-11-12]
hardware/Electrical/CADDeck_Knob/Knob.step
23.7 x 23.4 x 15.2 mm
Schablone PCB

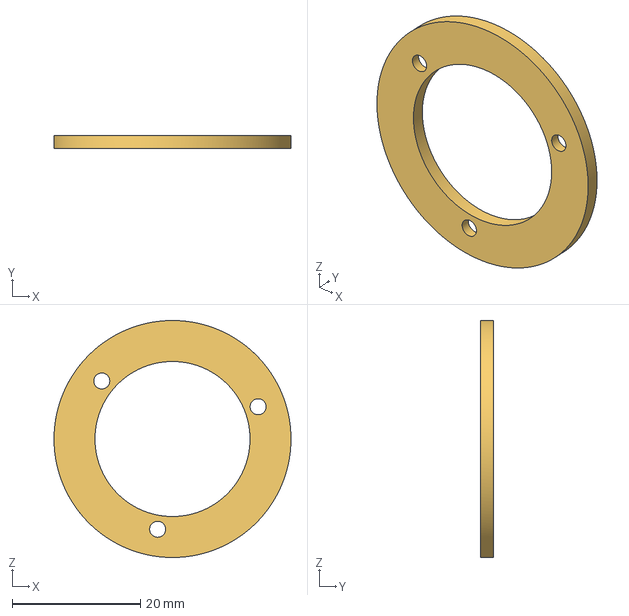
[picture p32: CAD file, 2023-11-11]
hardware/Case/Platte.3mf
37.0 x 2.00 x 37.0 mm

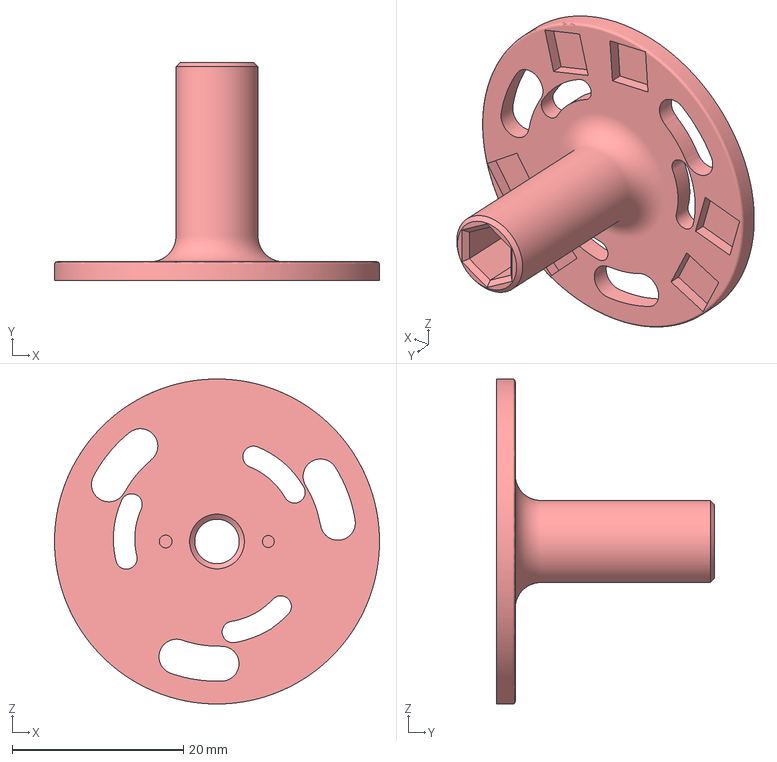
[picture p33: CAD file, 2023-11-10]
hardware/Case/Grundplatte.3mf
38.0 x 25.5 x 38.0 mm

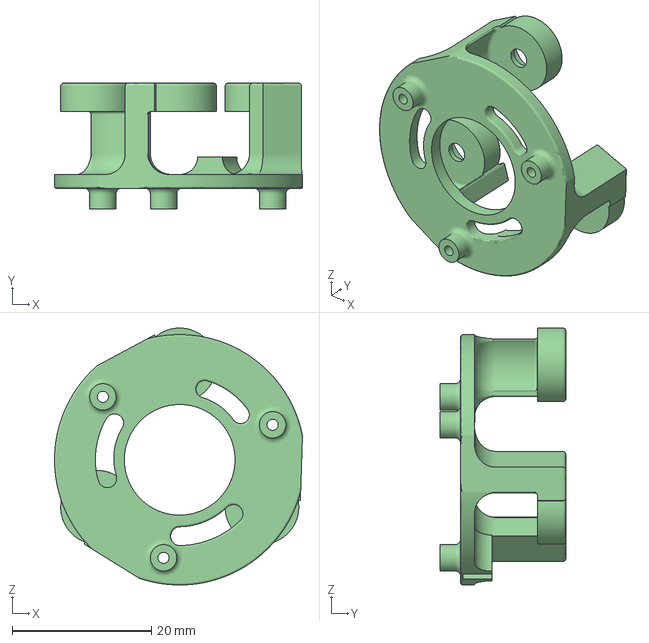
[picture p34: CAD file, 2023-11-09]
hardware/Case/Magnethalter.3mf
35.7 x 18.2 x 36.9 mm

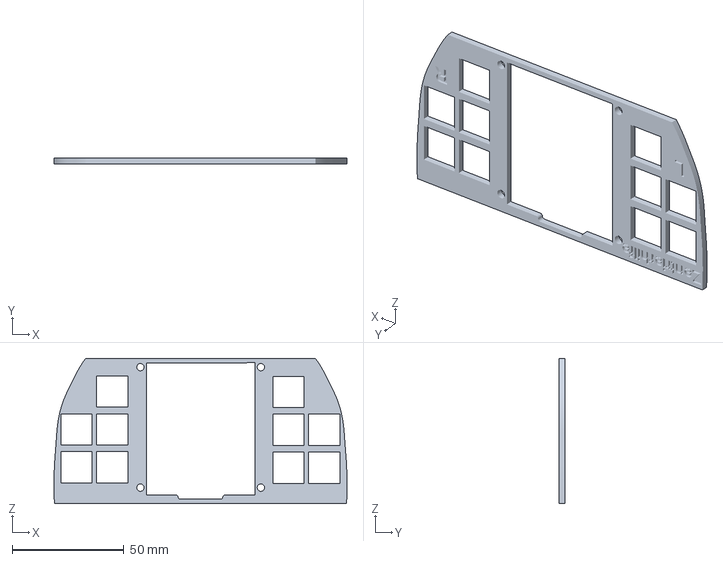
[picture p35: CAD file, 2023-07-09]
hardware/Case/Zentrierhilfe.3mf
131.3 x 2.50 x 65.1 mm

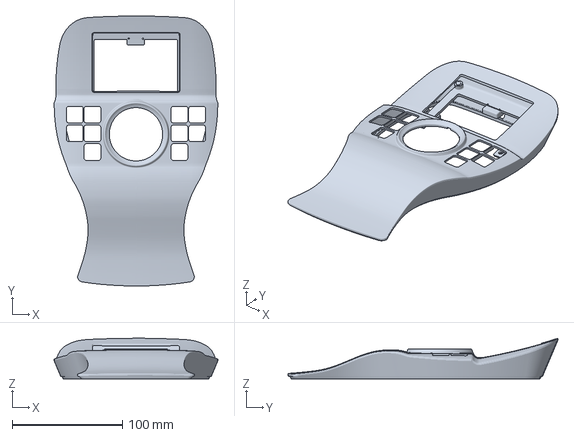
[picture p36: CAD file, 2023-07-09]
hardware/Case/Oben.3mf
148.6 x 245.2 x 36.8 mm

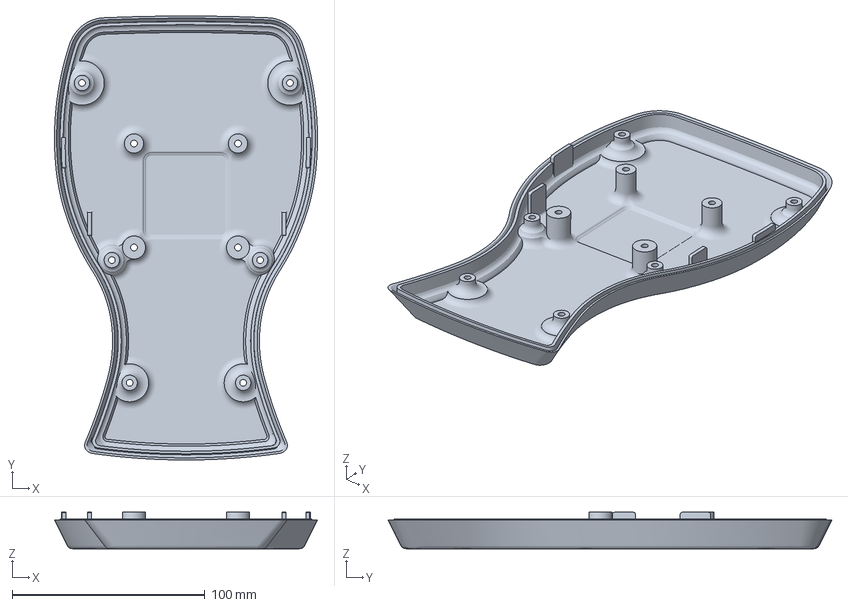
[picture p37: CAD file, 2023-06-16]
hardware/Case/Unten.3mf
136.6 x 230.6 x 19.0 mm

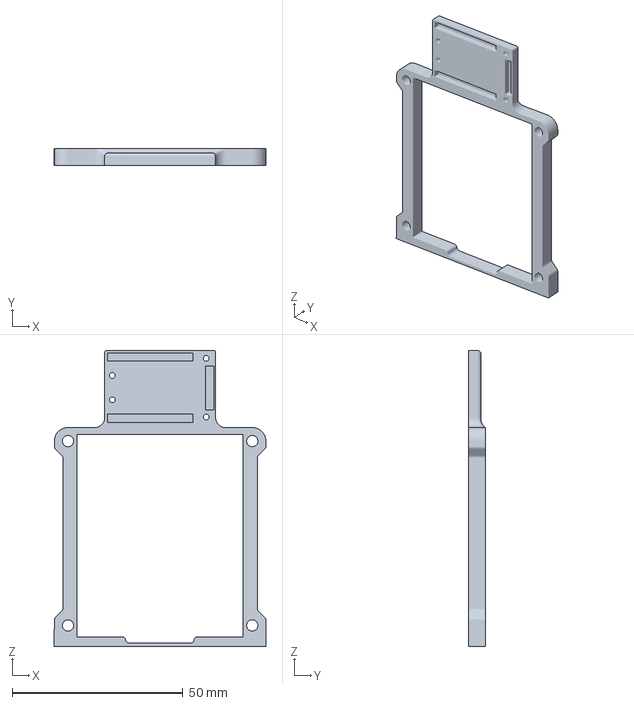
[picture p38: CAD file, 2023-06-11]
hardware/Case/Spacer frame without circuit board_without circuit board.3mf
62.1 x 4.86 x 86.7 mm

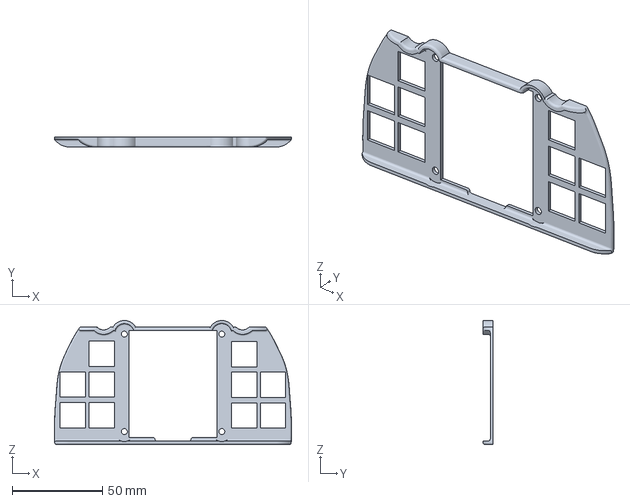
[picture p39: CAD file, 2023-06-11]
hardware/Case/Console without board.3mf
131.3 x 5.50 x 68.7 mm

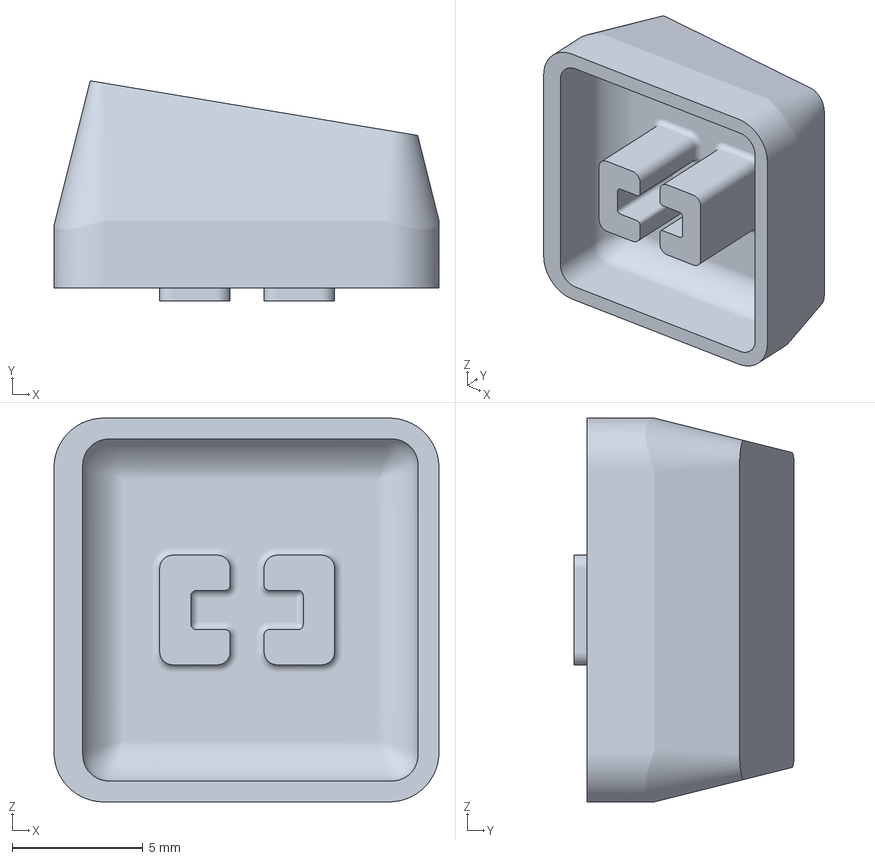
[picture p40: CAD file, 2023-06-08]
hardware/Case/F3 R Kappe.3mf
14.8 x 8.45 x 14.7 mm

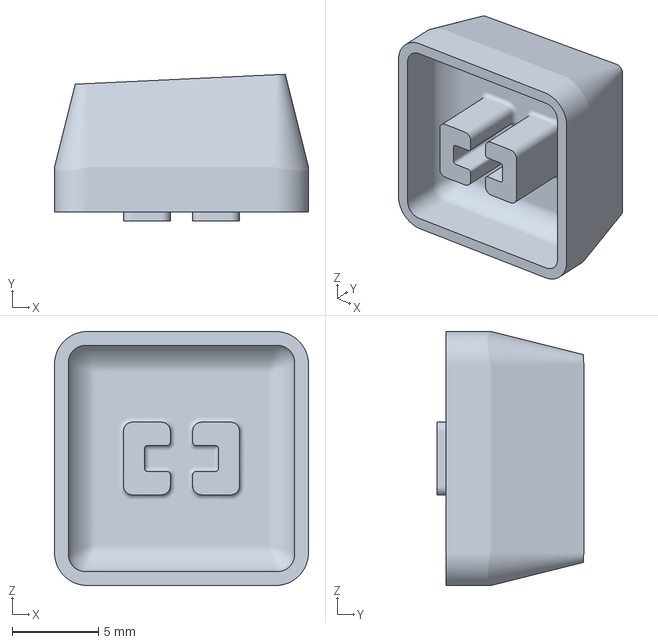
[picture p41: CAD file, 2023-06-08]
hardware/Case/F1 L Kappe.3mf
14.7 x 8.48 x 14.7 mm

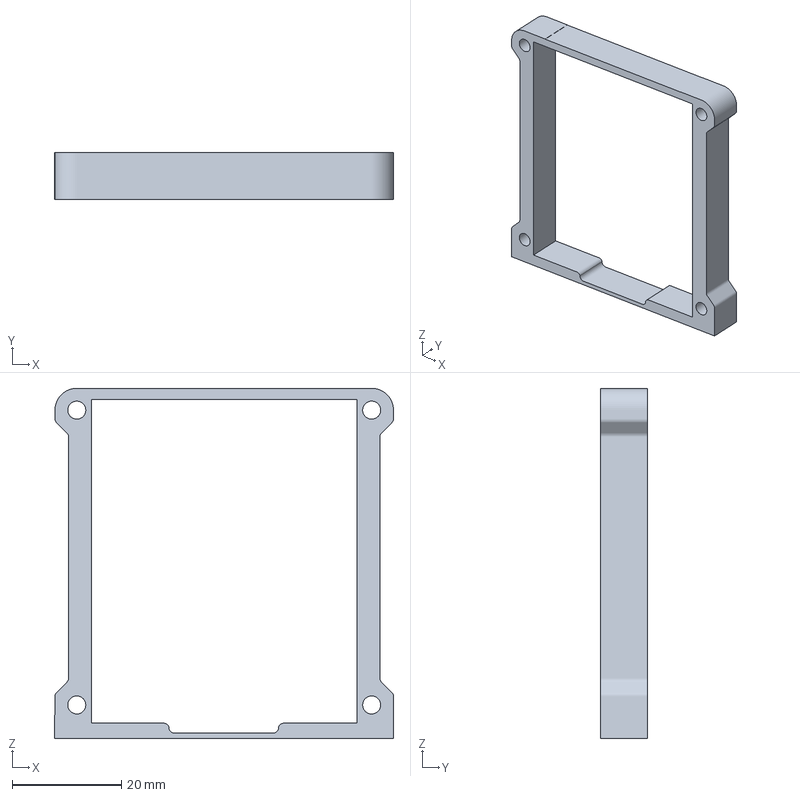
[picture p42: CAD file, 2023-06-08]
hardware/Case/Distanzrahmen.3mf
62.1 x 8.65 x 64.2 mm

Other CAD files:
hardware/Case/F2 R Kappe.3mf
hardware/Case/F5 L Kappe.3mf
hardware/Case/F3 L Kappe.3mf
hardware/Case/F5 R Kappe.3mf
hardware/Case/F2 L Kappe.3mf
hardware/Case/Abstandshalter 2x.3mf
hardware/Case/Abstandshalter_2x.3mf
hardware/Case/Dichtung_TPU Displ..3mf
hardware/Case/F1 R Kappe.3mf
hardware/Case/F4 L Kappe.3mf
hardware/Case/F4 R Kappe.3mf
hardware/Case/Hülse_3x.3mf
hardware/Case/Kabelklemme.3mf
hardware/Case/Kreutz.3mf
hardware/Case/Rad.3mf
hardware/Case/Steckerhalter.3mf
hardware/Case/Taster Kappe gerade 6x.3mf
hardware/Case/Taster Kappe schräg 4x.3mf
hardware/Model AFUDirk/Joystick/Joystick.f3d

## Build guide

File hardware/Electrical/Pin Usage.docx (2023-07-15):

Pin Usage

December 10, 2022

11:00 AM

GPIO | Input | Output | Function | ADC | DAC | RTC | Capacitive Touch | WT32-SC01 | CADDeck Std | CADDeck 10 Buttons | Notes
0 | pulled up | OK | | ADC2_CH1 | | RTC_GPI011 | T1 | I2S_MCLK (Available) | | | outputs PWM signal at boot, must be LOW to enter flashing mode
1 | TX pin | OK | | | | | | | | | debug output at boot
2 | OK | OK | | ADC2_CH2 | | RTC_GPI012 | T2 | Available | | | connected to on-board LED, must be left floating or LOW to enter flashing mode
3 | OK | RX pin | | | | | | | | | HIGH at boot
4 | OK | OK | | ADC2_CH0 | | RTC_GPI010 | T0
5 | OK | OK | | | | | | I2S_SCLK (Available) | | | outputs PWM signal at boot, strapping pin. I2S is a digital audio interface.
6 | x | x | (SCK/CLK) | | | | | | | | connected to the integrated SPI flash
7 | x | x | (SDO/SD0) | | | | | | | | connected to the integrated SPI flash
8 | x | x | (SDI/SD1) | | | | | | | | connected to the integrated SPI flash
9 | x | x | (SHD/SD2) | | | | | | | | connected to the integrated SPI flash
10 | x | x | (SWP/SD3) | | | | | | | | connected to the integrated SPI flash
11 | x | x | (CSC/CMD) | | | | | | | | connected to the integrated SPI flash
12 | OK | OK | | ADC2_CH5 | | RTC_GPI015 | T5 | (TFT_MISO) | | | boot fails if pulled high, strapping pin
13 | OK | OK | | ADC2_CH4 | | RTC_GPI014 | T4 | LCD_SDA (TFT_MOSI)
14 | OK | OK | | ADC2_CH6 | | RTC_GPI016 | T6 | Output LCD_SCL (TFT_SCLK) | | | outputs PWM signal at boot
15 | OK | OK | | ADC2_CH3 | | RTC_GPI013 | T3 | TFT_CS | | | outputs PWM signal at boot, strapping pin
16 | OK | OK | | | | | | Not available on WROVER-B
17 | OK | OK | | | | | | Not available on WROVER-B
18 | OK | OK | | | | | | I2C_SDA (TP,EM20918) | Also PC8575 SDA | Also PC8575 SDA | Pulled to 3.3V through 10k
19 | OK | OK | | | | | | I2C_SCL (TP,EM20918) | Also PC8575 SCL | Also PC8575 SCL | Pulled to 3.3V through 10k
21 | OK | OK | | | | | | Output LCD_RS
22 | OK | OK | | | | | | Input LCD_REST
23 | OK | OK | | | | | | Output - LCD_LED (Display brightness)
25 | OK | OK | | ADC2_CH8 | DAC1 | RTC_GPI06 | | I2S_LRCK (Available) | MX_LED | | I2S is a digital audio interface.
26 | OK | OK | | ADC2_CH9 | DAC2 | RTC_GPI07 | | I2S_DSDIN (Available) | | | I2S is a digital audio interface.
27 | OK | OK | | ADC2_CH7 | | RTC_GPI017 | T7 | Available | PCF8575 INT | PCF8575 INT
32 | OK | OK | | ADC1_CH4 | | RTC_GPI09 | T9 | Available | Roll (X) | Roll (X)
33 | OK | OK | | ADC1_CH5 | | RTC_GPI08 | T8 | Available | Pitch (Y) | Pitch (Y)
34 | OK | NO | | ADC1_CH6 | | RTC_GPI04 | | Available | ENC_2_A (future) | Rotate (Analog) | N o pullup resistor available
35 | OK | NO | | ADC1_CH7 | | RTC_GPI05 | | I2S_ASDOUT (Available) | ENC_2_B (future) | Zoom (Analog) | No pullup resistor available
36 | OK | NO | | ADC1_CH0 | | RTC_GPI00 | | SENSOR_VP, EM20918 EM_INT | | | No pullup resistor available
37 | | | | ADC1_CH1 | | | | Not available | | | Not Available on WROVER-B
38 | | | | ADC1_CH2 | | | | Not available | | | Not available on WROVER-B
39 | OK | NO | | ADC1_CH3 | | RTC_GPI03 | | Touch Interrupt, SENSOR_VN | | | No pullup resistor available

PCF8575 Pinout (10 Buttons)

Pin | Function | | Pin | Function | PCF8574 Pins
P0 | Push-Sensor Knob | | P8 | BUTTON_6 | PCB S/W
P1 | BUTTON_1 | | P9 | BUTTON_9 | P0-P7 = P0-P7
P2 | BUTTON_3 | | P10 | BUTTON_7 | P10-P17 = P8-P15
P3 | BUTTON_2 | | P11 | BUTTON_10
P4 | BUTTON_4 | | P12 | BUTTON_8
P5 | BUTTON_5 | | P13
P6 | | | P14
P7 | | | P15

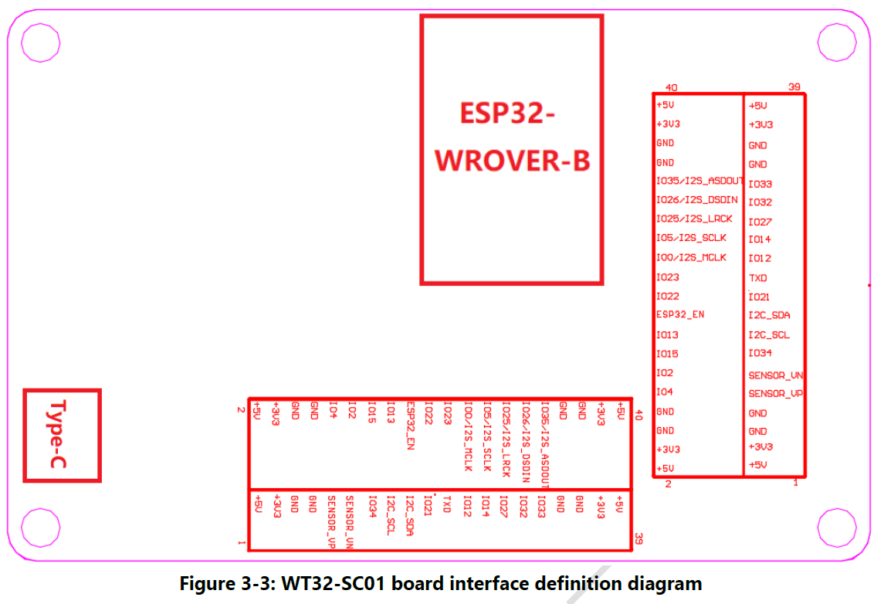
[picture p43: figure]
ESP32- WROVER-B o o o o o o o o o o 0 z +3U3 GND GND 1035/12s_asoou 1026/12S_OSDIN 105„12S SCI-K 100/12S_MCLK 1023 1022 ESP32_EN 1013 1015 104 GND GND 3143 39 *303 GNO GNO 1033 1032 1027 1014 1012 1021 12C_SDA 12C_SCL 1034 SENSOA_U SENSOR U GNO *303 Figure 3-3: WT32-SC01 board interface definition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
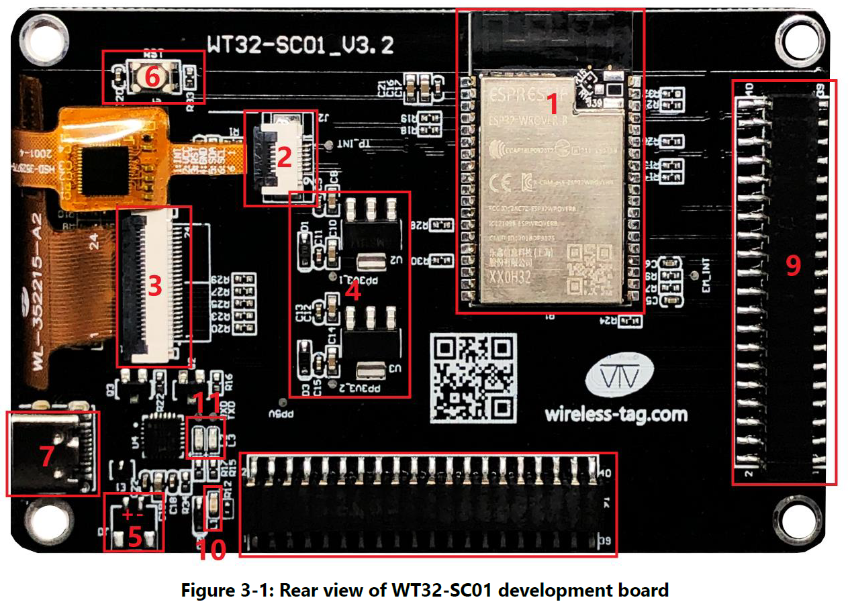
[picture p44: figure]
。 〒 い は ⅱ は な ⅱ い 20q 【 ODS ・ ZE ト M 」 0 」 2 ・ :L-E n6 こ Z ・ つ ー 日 OS ー Z の ト ユ

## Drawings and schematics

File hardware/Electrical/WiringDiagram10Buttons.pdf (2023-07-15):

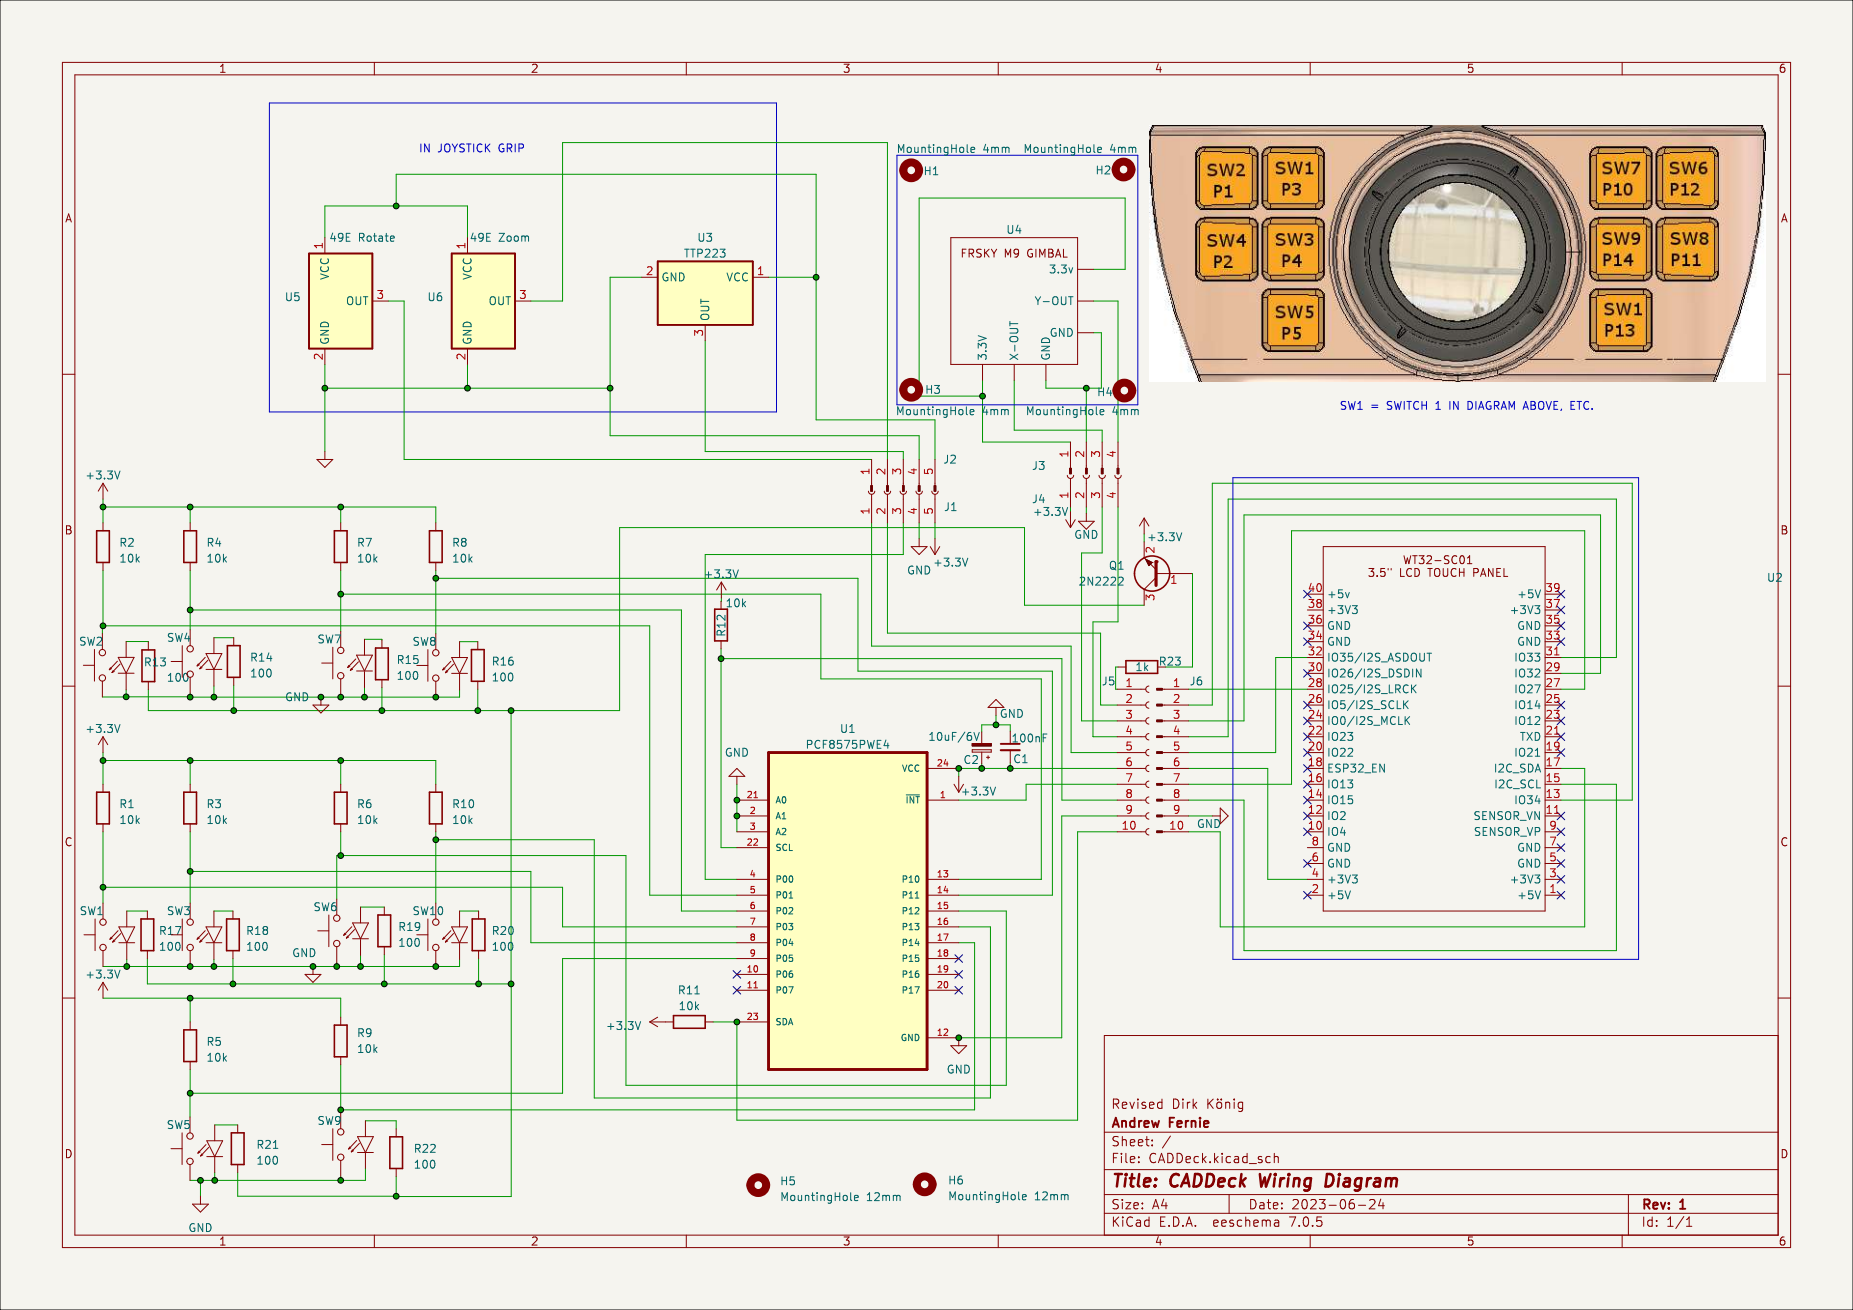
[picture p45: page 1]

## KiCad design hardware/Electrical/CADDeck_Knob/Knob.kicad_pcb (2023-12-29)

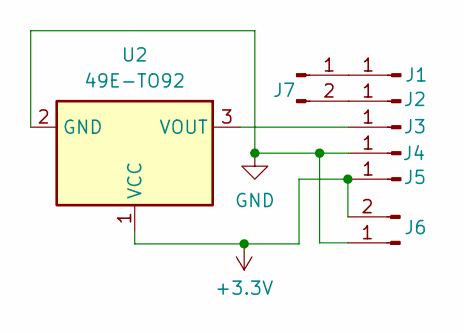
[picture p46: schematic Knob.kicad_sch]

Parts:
J1, J2, J3, J4, J5: Conn_01x01_Pin; Pin_D2.0mm_L3.0mm_FlatFork
J6, J7: Conn_01x02_Pin; PinHeader_1x02_P2.54mm_Vertical
U2: 49E-TO92

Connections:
+3.3V: J5.1, J6.2, U2.1 (VCC)
GND: J4.1, J6.1, U2.2 (GND)
unnamed: J1.1, J7.1
unnamed: J2.1, J7.2
unnamed: J3.1, U2.3 (VOUT)

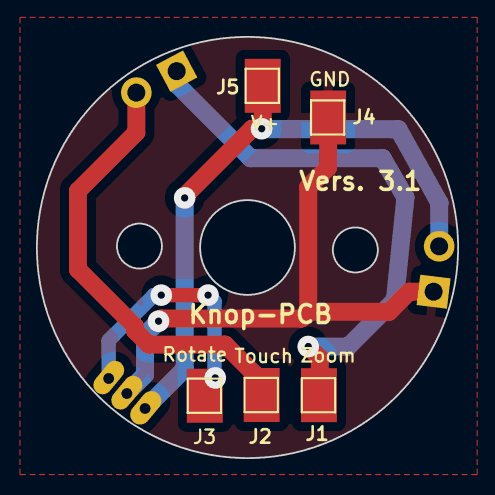
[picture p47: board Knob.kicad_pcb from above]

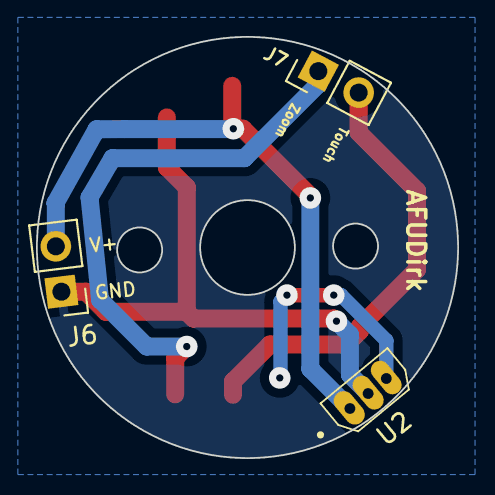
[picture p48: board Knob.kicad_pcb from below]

Board: 2 copper layers, 23.4 x 23.4 mm, 8 parts (3 on the bottom side), 5 nets.

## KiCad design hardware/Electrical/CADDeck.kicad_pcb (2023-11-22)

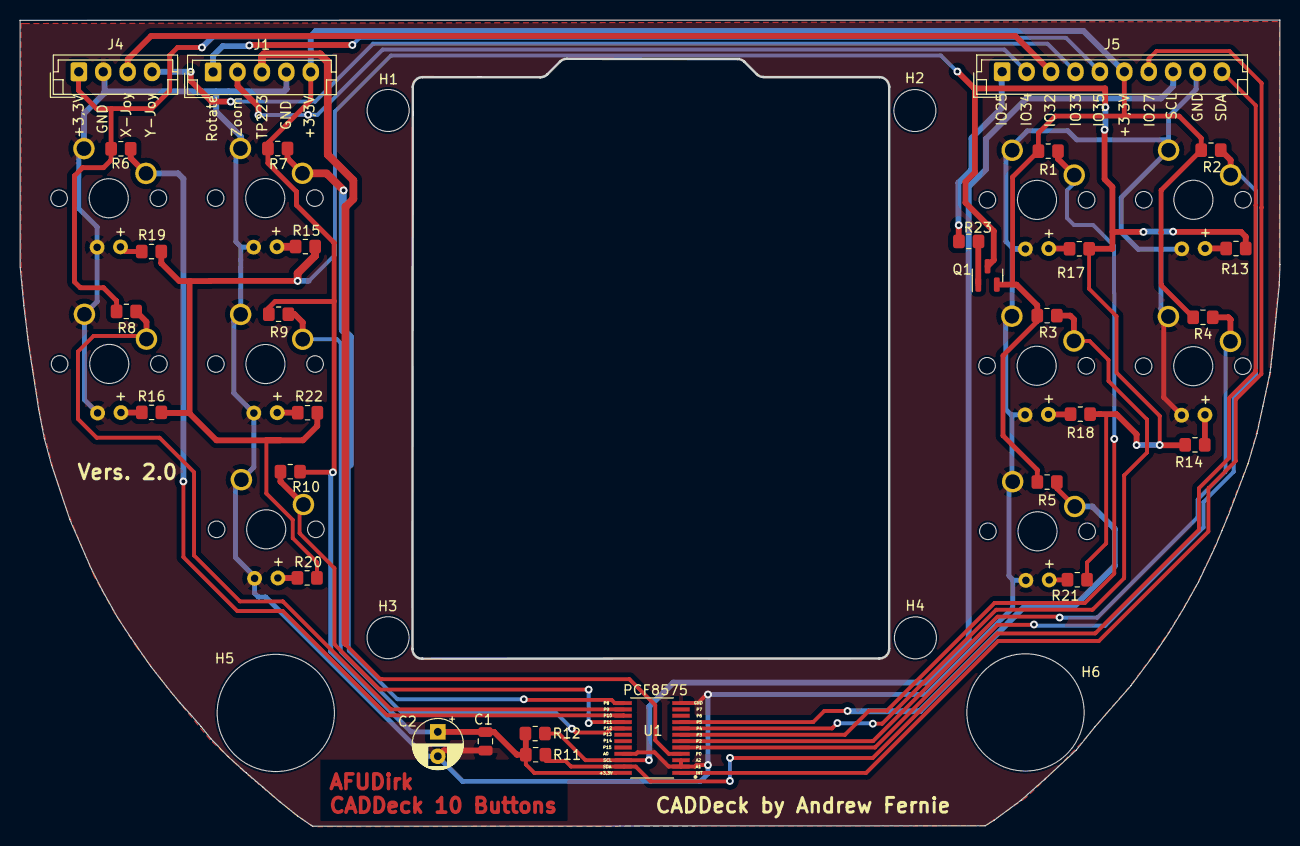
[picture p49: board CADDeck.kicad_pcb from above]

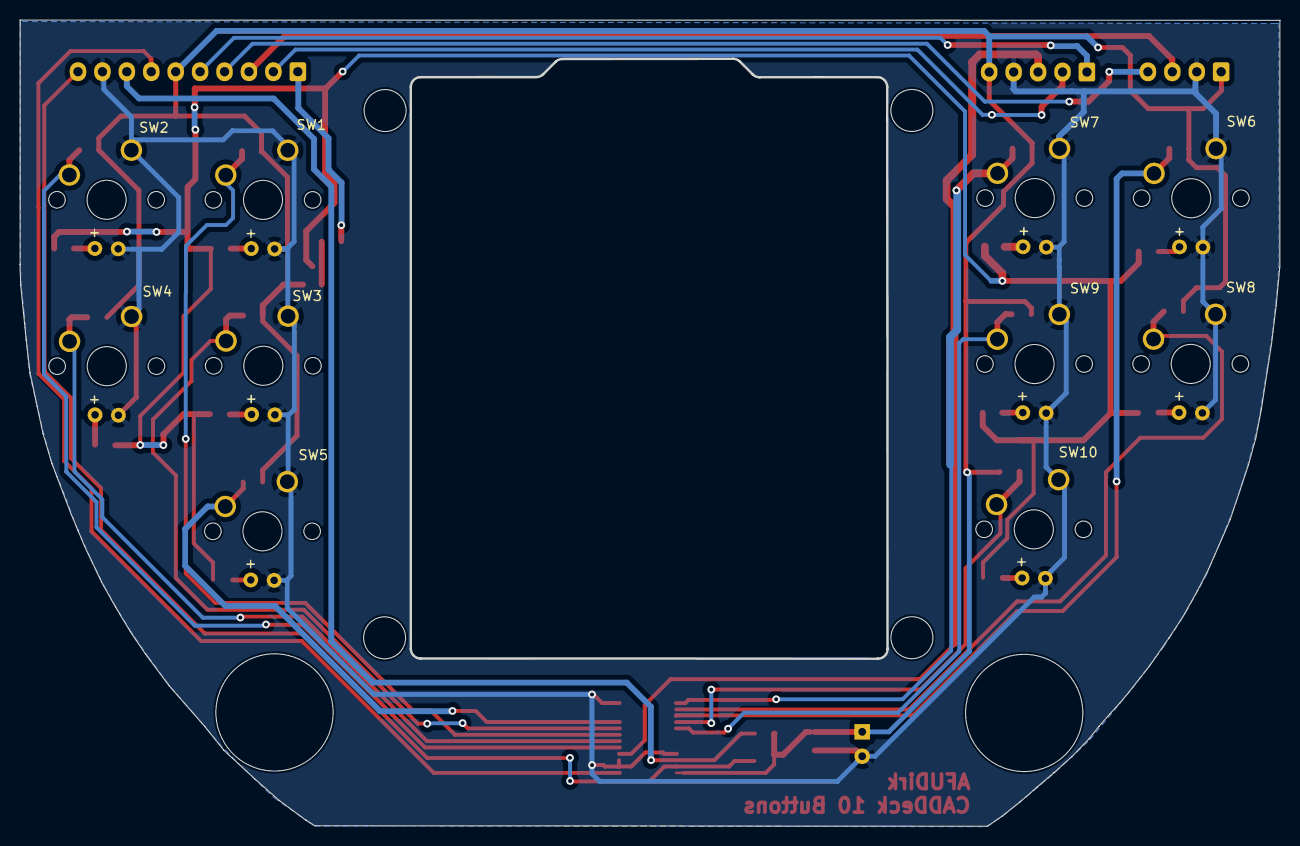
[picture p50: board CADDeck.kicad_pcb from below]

Board: 2 copper layers, 129.0 x 82.5 mm, 46 parts (10 on the bottom side), 33 nets.

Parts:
C1: 100nF; C_0805_2012Metric
C2: 10uF/6V; CP_Radial_D5.0mm_P2.50mm
H1, H2, H3, H4: MountingHole 4mm; MountingHole_4.3mm_M4
H5, H6: MountingHole 12mm; MountingHole_8.4mm_M8
J1: Conn_01x05_Socket; JST_EH_B5B-EH-A_1x05_P2.50mm_Vertical
J4: Conn_01x04_Socket; JST_EH_B4B-EH-A_1x04_P2.50mm_Vertical
J5: Conn_01x10_Socket; JST_EH_B10B-EH-A_1x10_P2.50mm_Vertical
Q1: 2N2222; SOT-23
R1, R2, R3, R4, R5, R6, R7, R8, R9, R10, R11, R12: 10k; R_0805_2012Metric_Pad1.20x1.40mm_HandSolder
R13, R14, R15, R16, R17, R18, R19, R20, R21, R22: 100; R_0805_2012Metric_Pad1.20x1.40mm_HandSolder
R23: 1k; R_0805_2012Metric_Pad1.20x1.40mm_HandSolder
SW1, SW2, SW3, SW4, SW5, SW6, SW7, SW8, SW9, SW10: SW_Push; Cherry_MX_LED
U1: PCF8575PWE4; SOP65P640X120-24N

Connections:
+3.3V: C1.2, C2.1, J1.5, J4.1, J5.6, Q1.2 (E), R1.1, R2.1, R3.1, R4.1, R5.1, R6.1, R7.1, R8.1, R9.1, R10.1, R11.1, R12.1, U1.24 (VCC)
GND: C1.1, C2.2, J1.4, J4.2, J5.9, SW1.1, SW1.3 (Kathode_-), SW2.1, SW2.3 (Kathode_-), SW3.1, SW3.3 (Kathode_-), SW4.1, SW4.3 (Kathode_-), SW5.1, SW5.3 (Kathode_-), SW6.1, SW6.3 (Kathode_-), SW7.1, SW7.3 (Kathode_-), SW8.1, SW8.3 (Kathode_-), SW9.1, SW9.3 (Kathode_-), SW10.1, SW10.3 (Kathode_-), U1.2 (A1), U1.3 (A2), U1.12 (GND), U1.21 (A0)
unnamed: J1.1, J5.5
unnamed: J1.2, J5.2
unnamed: J1.3, U1.4 (P00)
unnamed: J4.3, J5.3
unnamed: J4.4, J5.4
unnamed: J5.1, R23.1
unnamed: J5.7, U1.1 (~INT)
unnamed: J5.8, R12.2, U1.22 (SCL)
unnamed: J5.10, R11.2, U1.23 (SDA)
unnamed: Q1.1 (B), R23.2
unnamed: Q1.3 (C), R13.2, R14.2, R15.2, R16.2, R17.2, R18.2, R19.2, R20.2, R21.2, R22.2
unnamed: R17.1, SW1.4 (Anode_+)
unnamed: R13.1, SW2.4 (Anode_+)
unnamed: R18.1, SW3.4 (Anode_+)
unnamed: R14.1, SW4.4 (Anode_+)
unnamed: R21.1, SW5.4 (Anode_+)
unnamed: R19.1, SW6.4 (Anode_+)
unnamed: R15.1, SW7.4 (Anode_+)
unnamed: R16.1, SW8.4 (Anode_+)
unnamed: R22.1, SW9.4 (Anode_+)
unnamed: R20.1, SW10.4 (Anode_+)
unnamed: R2.2, SW2.2, U1.5 (P01)
unnamed: R4.2, SW4.2, U1.6 (P02)
unnamed: R1.2, SW1.2, U1.7 (P03)
unnamed: R3.2, SW3.2, U1.8 (P04)
unnamed: R5.2, SW5.2, U1.9 (P05)
unnamed: R7.2, SW7.2, U1.13 (P10)
unnamed: R8.2, SW8.2, U1.14 (P11)
unnamed: R6.2, SW6.2, U1.15 (P12)
unnamed: R10.2, SW10.2, U1.16 (P13)
unnamed: R9.2, SW9.2, U1.17 (P14)

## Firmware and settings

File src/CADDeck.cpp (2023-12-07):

/*                                          CADDeck

    Author: Andrew Fernie
    Date: 2023-05-20

    CADDeck is a combined joystick and touch panel display suitable for use with common CAD programs. It includes:

        1. Two axis joystick (e.g. for X, Y pan)
        2. Thumbwheel encoder in the joystick grip (e.g. for zoom) with push switch (e.g. for select)
        3. Four switches around joystick grip (e.g. hold one down while moving joystick for pan and another for rotate)
        4. Four switches around the base (e.g. measure, ESC...)
        5. LCD touch panel with up to 10 screens of 12 buttons

    All H/W buttons as well as the touch panel buttons are programmable through a web page.

    It connects to the PC via Bluetooth using the HID interface (i.e. it looks like a keyboard and mouse to the PC).
    A USB-C port is provided for power and to download code.

    This project is derived from TouchDeck by Dustin Watts. The original TouchDeck project is available at:
    https://github.com/DustinWatts/FreeTouchDeck
r
*/

/*
  Author: Dustin Watts
  Date: 27-08-2020

  My thanks goes out to Brian Lough, Colin Hickey, and the people on my Discord server
  for helping me a lot with the code and troubleshooting! https://discord.gg/RE3XevS

  FreeTouchDeck is based on the FreeDeck idea by Koriwi. It uses the TFT_eSPI library
  by Bodmer for the display and touch functionality and it uses an ESP32-BLE-Keyboard fork
  with a few modifications. For saving and loading configuration it uses ArduinoJson V6.

  FreeTouchDeck uses some libraries from other sources. These must be installed for
  FreeTouchDeck to compile and run.

  These are those libraries:

      !----------------------------- Library Dependencies --------------------------- !
      - Adafruit-GFX-Library (tested with version 1.10.4), available through Library Manager
      - TFT_eSPI (tested with version 2.4.70), available through Library Manager
      - ESPAsyncWebserver (latest version) download from: https://github.com/me-no-dev/ESPAsyncWebServer
      - AsyncTCP (latest version) download from: https://github.com/me-no-dev/AsyncTCP
      - ArduinoJson (tested with version 6.17.3), available through Library Manager
      ---One difference from the original FreeTouchDeck is that this program needs to send
        - both mouse and keyboard events. For this it uses the ESP32-BLE-Combo library
        - ESP32-BLE-Combo download from: https://github.com/BlynkGO/ESP32-BLE-Combo
        - However, the basic download is missing a number of key codes in BLEComboKeyboard.h.
        - I have added these key codes in the version of the library contained in the "lib"
        - folder of this project. If you want to use the original library, you will need to
        - correct the key codes yourself.


      --- If you use capacitive touch screen you will also need a library for that
      - The WT32-SC01 appears to be a FT6336, but works with both of the following libraries
      - Dustin Watts FT6236 Library (version 1.0.2), https://github.com/DustinWatts/FT6236
      - or the FT6336U library (https://github.com/aselectroworks)
      - You can select which library to use in the CADDeck.h file

  !-- Make sure you have setup your TFT display and ESP setup correctly in platformio.ini

        Select the right screen driver and the board (ESP32 is the only one tested) you are
        using. Also make sure TOUCH_CS is defined correctly. TFT_BL is also needed!

*/
#include "CADDeck.h"

#include <Arduino.h>

const char *versionnumber = "10Button V1.1.4";

/*
 * Version V1.1.4
 *                   - Use stack properly (push current page number then change it, and pop when returning to previous page)
 * 
 * Version V1.1.3
 *                   - Started work on support for multiple H/W buttons held down at the same time
 *                   - Renamed BLE device to "CADDeck"
 *                   - Fixed issues with "return to previous page" stack when not on page 0 at start
 *                   - removed a bunch of MSG_DEBUG statements
 *                   - Added images with my SpaceMouse button assignments for Solidworks and F360, and included
 *                     corresponding 3dxz files that can be imported in the 3dx settings app.
 *
 * Version V1.1.2
 *                   - Fix issues with H/W button description handling (wasn't saving, and possible buffer overflows)
 *                   - Prevent possible buffer overflow in filenames (mainly logos)
 *
 * Version V1.1.1
 *                   - Enable knob push/pull (vertical move) while in rotation mode and knob rotate when in translation mode
 *                   - Add SpaceMouse soft button support to configurator
 *
 * Version V1.1
 *                   - Added code for Spacemouse output to serial port. Needs to be hooked up to a Raspberry Pi Pico running this code
 *                     https://github.com/andrewfernie/magellan-spacemouse
 *
 * Version 1.0.0_10Button
 *                   - Using button numbering scheme as defined by AFUDirk
 *                   - Added controllable GPIO pin for LEDs on 10 button card
 *                   - Some messages (in ConfigHelper.cpp) can be displayed in English or German (compile time option). Does not apply
 *                     to messages on web pages, only those stored directly in the C++ code. Will eventually add the rest of AFUDirk's
 *                     messages, but want to look at how to do this in a more elegant way.
 *                   - Support for "click" and "double click" action for button on top of joystick (button 0).
 *                   - Added enumerations for actions. Makes code more readable, but not tied to the values in the
 *                     configurator and configuration json files, so these must be kept alienged manually.
 *
 * Version 0.0.17.10Button
 *                   - Added controllable GPIO functions
 *
 * Version 0.0.13.10Button
 *                   - Removed unneeded configurator code that was previously used to define which buttons were selecting
 *                     joystick actions
 *
 * Version 0.0.12.10Button
 *                   - Fix initialization of active CAD program for configurator
 *                   - Disable sleep timer to see if this is the cause of losing bluetooth connection
 *                   - To help setup debug, the default behavior of button_1 to button_10 (not including button 0) in
 *                     cadparams.json is to send a letter "a" through "j". This can be changed in the configurator.
 *
 * Version 0.0.11.10Button
 *                   - Zoom control active without pushing button
 *
 * Version 0.0.10.10Button
 *                   - Added hardcoded control functionality for Solidworks, Fusion360, Blender, FreeCAD, and AC3D
 *
 * Version 0.0.9.10Button.WIP
 *                   - More support for 10 buttons, analog zoom control, and analog rotate control. Hardcoded for Fusion360 only.
 *
 * Version 0.0.8.10Button.WIP
 *                   - Added support for 10 buttons, analog zoom control, and analog rotate control
 *
 * Version 0.0.7     - Adapted for four button knob.
 *                   - Added support for AC3D as fifth CAD program
 *
 * Version 0.0.6     - Add top status bar with BT link status and active CAD program
 *
 * Version 0.0.5     - Integrated thumbwheel encoder. The encoder is connected directly to the ESP32 as there were problems with getting the
 *                     interrupts working properly with the encoder functions in the PCF857X library.
 *                   - Using "PCF857X" library for I2C IO expander. This came from the PCF8574 library, but has
 *                     been modified to support the PCF8575. The PCF8575 is a 16-bit IO expander, but the library
 *                     for the PCF8575 was well behind the PCF8574 library functionality. A #define statement in
 *                     the PCF857X library allows the library to be used for both the PCF8574 and PCF8575.
 *                   - Overall, working well. Next steps are:
 *                      - Highlight the selected CAD program
 *                      - Get the web configrator up to date with all the changes made to the code
 *
 *
 * Version 0.0.4     - Allow any menu to be displayed on startup. Previously, the default menu had to be menu0.json
 *                   - h/w button function definitions in cadparams.json
 *                   - CAD program selection in cadparams.json
 *                   - Joystick functionality for pan, rotate, zoom working
 *
 * Version 0.0.3     - Basic joystick functionality for pan, rotate, zoom
 *
 * Version 0.0.2     - Updated to use ESP32-BLE-Combo so that Mouse events can be sent as well as Keyboard events
 *
 * Version 0.0.1     - Starting from FreeTouchDeckWT32 V0.2.1-AF
 *
 * Version 0.2.0-AF  - Merge pull request that improves key spacing calculations by adding a margin around the screen.
 *
 * Version 0.1.12-AF - Use PSRAM to save logos and draw directly from PSRAM to screen. Overall, drawing a 4x3 keypad goes from about 2.2s to about 1.1s
 *                     the first time the menu is accessed down to about 0.2s all future times.
 *
 * Version 0.1.11-AF - Improved algorithm for calculating button size from key spacing rather than key spacing from button size
 *                   - Added espressif32 version requirement to the platform_packages callout (not needed on some platforms, but
 *                     this should make it more compatible across development platforms)
 *                   - Changed the WiFi connect code to show the SSID and Password that is being used to connect. The password display
 *                     is dependent on defining WIFI_PASSWORD_DISPLAY, and is disabled by default
 * Version 0.1.10-AF - Support for both WT32-SC01 and generic H/W configurations. Some sample configurations are provided.
 *                   - Don't draw inactive buttons. Inactive means the logo is blank.bmp and there are no actions defined.
 *
 * Version 0.1.9-AF  - Fix to variables in wificonfig.json. Defined TOUCH_CS to avoid warning.
 *
 * Version 0.1.8-AF  - Added support for FT6236 capacitive touch screen libraryOSO
 *
 * Version 0.1.7-AF  - Fix menu1.json for brightness down button code
 *
 * Version 0.1.6-AF  - A.Fernie 2022-09-09
 *    Updates to codes sent on com port for each button press
 *
 * Version 0.1.5-AF  - A.Fernie 2022-08-27
 *    Added USB Comms functionality (like FreeTeamsDeck)
 *
 * Version 0.1.4-AF  - A.Fernie 2022-08-19
 *    Added ability to locally save general config. Allows
 *    SleepEnable status to be preserved without going through web page. Later on allow
 *    additional params like sleeptimer, colors, etc.
 *
 * Version 0.1.3-AF  - A.Fernie 2022-08-08
 *  Added monitoring of the voltage of an external battery
 *
 * Version 0.1.2-AF  - A.Fernie 2022-08-04
 * 1. Load config.json file (wasn't being read, so always used defaults)
 * 2. Fix logic for button background color so that it is based on the action for that button being
 *    a menu change or not
 * 3. Fix VSCode.bmp background color (was not completely back)
 * 4. Added some "[INFO]" messages for colors and sleepenable/sleeptimer. Note that yuou need to enable
 *    [INFO] messages by setting "#define LOG_MSG_LEVEL 3  // 1=ERROR, 2=ERROR+WARN, 3=ERROR+WARN+INFO"
 *    in CADDeck.h to see them
 * 5. No colons after [INFO], [WARN], [ERROR]
 *
 *
 * Version 0.1.1-AF  - A.Fernie 2022-07-18
 * 1. Store sample 3x5 menus
 * 2. Switch to 3x4 (more readable).
 *
 * Version 0.1.0-AF  - A.Fernie 2022-7-15
 *
 * Started from 0.9.16 and added/modified:
 * 1. Now iterates through arrays of buttons rather than using repeated code for each button in
 *    most cases. Still two sections in index.htm that use repeated code.
 * 2. Support up to a 3x5 array of buttons (limited by index.htm)
 * 3. Home page is no longer a special page that just links to five other pages, and the other pages
 *    are no longer simply five action buttons plus a link back to the home page. All buttons on
 *    each page can be actions or links. Just make sure you always have a way back.
 * 4. There are now 10 pages. This includes Menu0 (home).
 * 5. Updated to latest platformio Arduino platform (2.x)
 * 6. Changed from SPIFFS to LittleFS. Note that if you check the serial monitor output you will see
 *    some error messages like "[vfs_api.cpp:104] open(): /littlefs/list does not exist". This is a
 *    known issue with ESPAsyncWebsServer related to LittleFS supporting folders while SPIFFS does not.
 *    see https://github.com/lorol/LITTLEFS/issues/2 for more on the topic.
 * 7. Currently only working on WT32-SC01 card http://www.wireless-tag.com/portfolio/wt32-sc01/
 *
 * Version 0.9.16.
 *
 * Added UserActions. In the UserAction.h file there are a few functions you can define and
 * select through the configurator. The functions have to written before compiling. These functions
 * are then hardcoded. Look at UserActions.h for some examples.
 *
 * Added some missing characters.
 */

#ifdef USECAPTOUCH
#ifdef USE_FT6336U_LIB
#ifdef CUSTOM_TOUCH_SDA
FT6336U ts = FT6336U(PIN_SDA, PIN_SCL);
#else
FT6336U ts = FT6336U();
#endif
#else
FT6236 ts = FT6236();
#endif
#endif

AsyncWebServer webserver(80);

TFT_eSPI tft = TFT_eSPI(SCREEN_HEIGHT, SCREEN_WIDTH);  // Apparently the display is a portrait mode, but we want landscape

Preferences savedStates;

// placeholder for the pagenumber we are on (0 indicates home)
int pageNum = 0;
Stack pageHistoryStack(10);

// Initial LED brightness
int ledBrightness = 255;

// path to the directory the logo are in ! including leading AND trailing / !
char logopath[64] = "/logos/";

// templogopath is used to hold the complete path of an image. It is empty for now.
char templogopath[64] = "";

// Create instances of the structs
Menu menu[NUM_PAGES];

Wificonfig wificonfig;

Config generalconfig;
CADConfig cadconfig;
CADProgramConfig cadprogramconfig[NUM_CAD_PROGRAMS];

Generallogos generallogo;

unsigned long previousMillis = 0;
unsigned long Interval = 0;
bool displayinginfo = false;
bool displayingIOValues = false;
bool displayingButtonDescriptions = false;

char jsonFileFail[LEN_FILENAME] = "";

bool psramAvailable = false;

uint8_t last_hwbutton_state[NUM_HW_BUTTONS] = {0, 0, 0, 0, 0, 0, 0, 0, 0, 0, 0};

// Invoke the TFT_eSPI button class and create all the button objects
TFT_eSPI_Button key[BUTTON_ROWS][BUTTON_COLS];

#ifdef READ_EXTERNAL_BATTERY
float readExternalBattery();
float externalBatteryVoltage = 0.0;
long lastADCRead = 0;
#endif
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
void loop(void)
{
    bool pressed = false;
    uint16_t t_x = 0, t_y = 0;
    uint8_t status;

    if (millis() > (last_loop_start + loop_period)) {
        this_loop_start = millis();
        loop_count++;

        // Update and handle the joystick and physical buttons
        update_io();

        // Check and handle any commands from the serial port
        serial_commands();

        // The SpaceMouse Pro button reset
        spaceMouse.ClearButtonMask();

        // Handle the touch screen
#ifdef USECAPTOUCH
#ifdef USE_FT6336U_LIB
        FT6336U_TouchPointType touchPos;
        touchPos = ts.scan();

        if (touchPos.tp[0].tapped) {
            MSG_TOUCH_DEBUG(" Tap Detected: ");
            MSG_TOUCH_DEBUGLN(touchPos.touch_count);
            MSG_TOUCH_DEBUG(" pageNum: ");
            MSG_TOUCH_DEBUGLN(pageNum);
            MSG_TOUCH_DEBUG(" x,y: ");
            MSG_TOUCH_DEBUG(touchPos.tp[0].x);
            MSG_TOUCH_DEBUG(" : ");
            MSG_TOUCH_DEBUGLN(touchPos.tp[0].y);

            // Flip things around so it matches our screen rotation
            //         p.x = map(p.x, 0, 320, 320, 0);

            t_x = touchPos.tp[0].y;
            t_y = 320 - touchPos.tp[0].x;
            pressed = true;
        }
        else {
            pressed = false;
        }
#else
        if (ts.touched()) {
            // Retrieve a point
            TS_Point p = ts.getPoint();

            // Flip things around so it matches our screen rotation
            p.x = map(p.x, 0, 320, 320, 0);
            t_y = p.x;
            t_x = p.y;

            pressed = true;
        }
        else {
            pressed = false;
        }
#endif
#else
        pressed = tft.getTouch(&t_x, &t_y);
#endif

        if (pageNum == WEB_REQUEST_PAGE) {
            // If the pageNum is set to NUM_PAGES+1, do not draw anything on screen or check for touch
            // and start handling incomming web requests.
        }
        else if (pageNum == SPECIAL_PAGE_INFO) {
            if (!displayinginfo) {
                printinfo();
            }

            if (pressed) {
                displayinginfo = false;

                pageNum = pageHistoryStack.pop(&status);
                if(!isValidPageNumber(pageNum)){
                    MSG_ERROR1("[ERROR] Invalid page number: ", pageNum);
                    pageNum = 0;
                }
                else if (status == STACK_STATUS_EMPTY) {
                    MSG_ERRORLN("[ERROR] Page History Stack is empty. Cannot pop page so switching to home page.");
                    pageNum = 0;
                }

                tft.fillScreen(generalconfig.backgroundColour);
                drawKeypad();
            }
        }
        else if (pageNum == SPECIAL_PAGE_IO_MONITOR) {
            printIOValues();

            if (pressed) {
                displayingIOValues = false;
                pageNum = pageHistoryStack.pop(&status);

                if (!isValidPageNumber(pageNum)) {
                    MSG_ERROR1("[ERROR] Invalid page number: ", pageNum);
                    pageNum = 0;
                }
                else if (status == STACK_STATUS_EMPTY) {
                    MSG_ERRORLN("[ERROR] Page History Stack is empty. Cannot pop page so switching to home page.");
                    pageNum = 0;
                }

                tft.fillScreen(generalconfig.backgroundColour);
                drawKeypad();
            }
        }
        else if (pageNum == SPECIAL_PAGE_BUTTON_INFO) {
            if (!displayingButtonDescriptions) {
                printButtonInfo(cadconfig.current_program);
            }

            if (pressed) {
                displayingButtonDescriptions = false;

                pageNum = pageHistoryStack.pop(&status);
                if (!isValidPageNumber(pageNum)) {
                    MSG_ERROR1("[ERROR] Invalid page number: ", pageNum);
                    pageNum = 0;
                }
                else if (status == STACK_STATUS_EMPTY) {
                    MSG_ERRORLN("[ERROR] Page History Stack is empty. Cannot pop page so switching to home page.");
                    pageNum = 0;
                }

                tft.fillScreen(generalconfig.backgroundColour);
                drawKeypad();
            }
        }
        else if (pageNum == SPECIAL_3_PAGE) {
            // We were unable to connect to WiFi. Waiting for touch to get back to the settings menu.

            if (pressed) {
                // Return to Settings page
                displayinginfo = false;

                pageNum = pageHistoryStack.pop(&status);
                if (!isValidPageNumber(pageNum)) {
                    MSG_ERROR1("[ERROR] Invalid page number: ", pageNum);
                    pageNum = 0;
                }
                else if (status == STACK_STATUS_EMPTY) {
                    MSG_ERRORLN("[ERROR] Page History Stack is empty. Cannot pop page so switching to home page.");
                    pageNum = 0;
                }

                tft.fillScreen(generalconfig.backgroundColour);
                drawKeypad();
            }
        }
        else if (pageNum == SPECIAL_4_PAGE) {
            // A JSON file failed to load. We are drawing an error message. And waiting for a touch.

            if (pressed) {
                // Load home screen
                displayinginfo = false;

                pageNum = pageHistoryStack.pop(&status);
                if (!isValidPageNumber(pageNum)) {
                    MSG_ERROR1("[ERROR] Invalid page number: ", pageNum);
                    pageNum = 0;
                }
                else if (status == STACK_STATUS_EMPTY) {
                    MSG_ERRORLN("[ERROR] Page History Stack is empty. Cannot pop page so switching to home page.");
                    pageNum = 0;
                }
                tft.fillScreen(generalconfig.backgroundColour);
                drawKeypad();
            }
        }
        else {
            // Check if sleep is enabled and if our timer has ended.

#ifdef TOUCH_INTERRUPT_PIN
            if (generalconfig.sleepenable) {
                if (millis() > previousMillis + Interval) {
                    // The timer has ended and we are going to sleep  .
                    tft.fillScreen(TFT_BLACK);
                    MSG_INFOLN("[INFO] Going to sleep.");
#ifdef speakerPin
                    if (generalconfig.beep) {
                        ledcAttachPin(speakerPin, 2);
                        ledcWriteTone(2, 1200);
                        delay(150);
                        ledcDetachPin(speakerPin);
                        ledcWrite(2, 0);

                        ledcAttachPin(speakerPin, 2);
                        ledcWriteTone(2, 800);
                        delay(150);
                        ledcDetachPin(speakerPin);
                        ledcWrite(2, 0);

                        ledcAttachPin(speakerPin, 2);
                        ledcWriteTone(2, 600);
                        delay(150);
                        ledcDetachPin(speakerPin);
                        ledcWrite(2, 0);
                    }
#endif
                    MSG_INFOLN("[INFO] Saving latched states");

                    esp_sleep_enable_ext0_wakeup(TOUCH_INTERRUPT_PIN, 0);
                    esp_deep_sleep_start();
                }
            }
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

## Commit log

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2023-03-17 Fertig gestellt
    Fertig gestellt
    [Abstandshalter_1.3mf, Abstandshalter_2.3mf, Case Bottom Front.stl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]
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2023-03-17 Hatte noch einen Fehler
    die Tiefe vom Magnet geändert
    [Kreutz.3mf]
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2023-03-21 Nur ein paar Verfeinerungen
    [Joystick.f3d, Kabelklemme.3mf, Magnethalter.3mf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]
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2023-03-23 Update Joystick.f3d
    Tolleranz verkleinert
    [Joystick.f3d]
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2023-03-23 Bohrung im Würfel verkleinert
    [Joystick.f3d, Würfel.3mf]
2023-03-23 Würfel Bohrung geändert durchgehend
    [Joystick.f3d, Würfel.3mf]
2023-03-23 Achse Würfel
    Zentrierbohrung angebracht
    [Achse (1).3mf, Joystick.f3d]
2023-03-24 Achsen geändert
    Flächen angebracht dien das mitdrehen verhindern
    [Achse (1).3mf, Achse Würfel.3mf, Achse.3mf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]
2023-03-24 Magnetjustage
    Es mussten einige Teile geändert werden, da ich andere Magnete und deren Position verändert habe. Muss erst noch testen, ob es jetzt funktioniert.
    [Innen.3mf, Joystick.f3d, Magnetplatte.3mf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]
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2023-03-24 Bohrungen an den Achsen geändert
    [Achse (1).3mf, Achse Würfel.3mf, Achse.3mf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]
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2023-03-25 Würfelbohrung und Achse geändert
    [Achse Würfel.3mf, Joystick.f3d, Würfel.3mf]
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2023-03-29 Grundplatte
    Magnetposition verändert, damit das Rad besser zentriert wird.
    [Grundplatte.3mf]
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2023-04-03 Update Platte.3mf
    Magnetanordnung geändert.
    [Platte.3mf]
2023-04-04 Delete Platte.3mf
    Der untere Hallsensor muss noch getestet werden.
    [Platte.3mf]
2023-04-05 Magnet Rotate neu angeordnet
    Platine in der Grundplatte verbessert die elektrische Verbindungsstabilität.
    [Magnethalter.3mf, Platine(Schablone).3mf]
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2023-04-17 Kleine Veränderungen
    und Bild aktualisiert
    [Deckel.3mf, Grundplatte.3mf, Kreutz.3mf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]
2023-04-17 Übersetzung
    Noch ein paar Zeilen ins deutsche übersetzt
    [Abstandshalter_1.3mf, Abstandshalter_2.3mf, Abstandshalter_2x.3mf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]
2023-04-20 Gewinde war gerissen
    Langmutter zur Verstärkung integriert
    [Abstandshalter_2x.3mf, Grundplatte.3mf, Kreutz.3mf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]
2023-04-21 Modell fertig gestellt
    Alle Teile passen mechanisch zusammen.
    Am Gehäuse Oberteil habe ich nur die Bohrung für den USB-C Anschluss vergrößert,
    diese erschien mir ein bisschen zu klein.
    [Deckel.3mf, Grundplatte.3mf, Grundplatte_m_Einsatz.3mf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]
2023-04-21 Belegungsplan korrigiert
    Hatte falsche Pinangaben für die 10 Tasten gemacht.
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2023-05-01 Aktuelle Version mit 10 Buttons
    [Abstandshalter 2x.3mf, Abstandshalter_1.3mf, Abstandshalter_2.3mf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]
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2023-05-15 Dateien für Platine hinzugefügt
    [Schablone-B_Cu.gbl, Schablone-B_Mask.gbs, Schablone-B_Paste.gbp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]
2023-05-18 Hallsensor hatte die falsche Bezeichnung
    [CADDeck.kicad_sch]
2023-05-19 Schaltplan aktualisiert
    Ist noch nicht ganz fertig um ein Board zu erstellen
    [CADDeck.kicad_pcb, CADDeck.kicad_sch]
2023-05-19 Platinen Erstellung in Arbeit
    [CADDeck.kicad_pcb, CADDeck.kicad_sch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]
2023-05-19 Update CADDeck.kicad_pcb
    Platine größer gemacht
    [CADDeck.kicad_pcb]
2023-05-21 Platine geroutet
    aber noch nicht auf Fehler überprüft
    [CADDeck.kicad_pcb, CADDeck.kicad_sch]
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2023-05-22 Platine aktualisiert
    LED Beleuchtung für Tasten
    [CADDeck.kicad_pcb, CADDeck.kicad_sch]
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2023-06-04 Board Transistor eingefügt
    Für LED Beleuchtung und Leiterbahnen angepasst.
    [CADDeck.kicad_pcb, CADDeck.kicad_sch]
2023-06-05 Platine optimiert
    und Gerberdateien aktualisiert.
    [CADDeck.kicad_pcb]
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2023-06-08 Platinenversion
    Dateien angepasst, damit die Platine ins Gehäuse passt.
    Die Schalterkappen habe ich auch etwas verändern müssen, damit die LED's in dem MX-Tastern passen, außerdem habe ich die Tasten außen etwas verkleinert, damit sie besser ins Gehäuse passen.
    [Distanzrahmen.3mf, F1 L Kappe.3mf, F1 R Kappe.3mf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]
2023-06-09 Stecker verrückt
    um mehr Platz an den Abstandshaltern zu bekommen.
    [CADDeck.kicad_pcb]
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2023-06-21 Platinenbeschriftung korrigiert
    [CADDeck.kicad_pcb]
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2023-06-29 LED Ansteuerung
    hatte eine falsche Verbindung am Transistor
    [CADDeck.kicad_pcb, CADDeck.kicad_sch]
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2023-07-05 Transistor geändert
    Bei KiCad war ein fehlerhafter Footprint.
    [CADDeck.kicad_pcb, CADDeck.kicad_sch]
2023-07-09 Habe am Modell nur ein paar Radien hinzugefügt.
    Und die Zentrierhilfe etwas dicker gemacht
    [Oben.3mf, Zentrierhilfe.3mf]
2023-07-14 PCG8575 A0-A1 auf GND gelegt
    Muss noch getestet werden, da der PCF nicht funktionierte.
    [CADDeck.kicad_pcb, CADDeck.kicad_sch]
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2023-11-09 Kleine Optimierungen am Knopf
    Bohrungen vergrößert und Führungen durch Abstandshalter ALU M2,5 x 15 mm ersetzt.
    [Grundplatte.3mf, Magnethalter.3mf]
2023-11-10 Geringfügige Änderung
    Position der Magnete geändert, damit es besser zu drucken ist.
    [Grundplatte.3mf]
2023-11-12 Knob Platine neu erstellt
    Lötpads anstelle eines Pinheaders angebracht, da wenig Platz unter dem Knob ist. Vereinfacht das Löten.
    [Knob.kicad_pcb, Knob.kicad_sch, Knob.step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]
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2023-11-26 Änderung am Deckel
    Der Touchsensor sollte nun einrasten und braucht nicht geklebt zu werden.
    Somit kann dieser zum Schluss eingebaut werden und erleichtert die Montage.
    [Deckel.3mf]
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
